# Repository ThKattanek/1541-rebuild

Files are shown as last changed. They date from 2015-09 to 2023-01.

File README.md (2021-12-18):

# 1541-rebuild
Ersetzt den Analogteil einer Floppy 1541 durch ein Micro Controller der Disk Images per SD Karte lesen kann. Mit dieser Hardware ist es möglich ein Board wo der Analogteil defekt ist, durch diese wieder zum laufen zu bringen. Das schreiben ist nun auch schon enthalten. Es wird lediglich die 1541 Platine, diese Hardware und ein 5VDC Netzteil benötigt, oder auch das Originale Netzteil. An der 1541 II Platine muss eine Änderungen vorgenommen werden und zwar die (VIA2 (DC) sockeln.

#### ** Danke [F00K42](https://github.com/fook42) für die Entwicklung der Schreibroutinen für D64 Images. **

### [Letzte Offizelle Version findet ihr hier](https://github.com/ThKattanek/1541-rebuild/releases/latest)

### Hardware / Schaltplan
Die Hardware wird mit KiCad entwickelt. Version 5.1.4 unter Ubuntu.

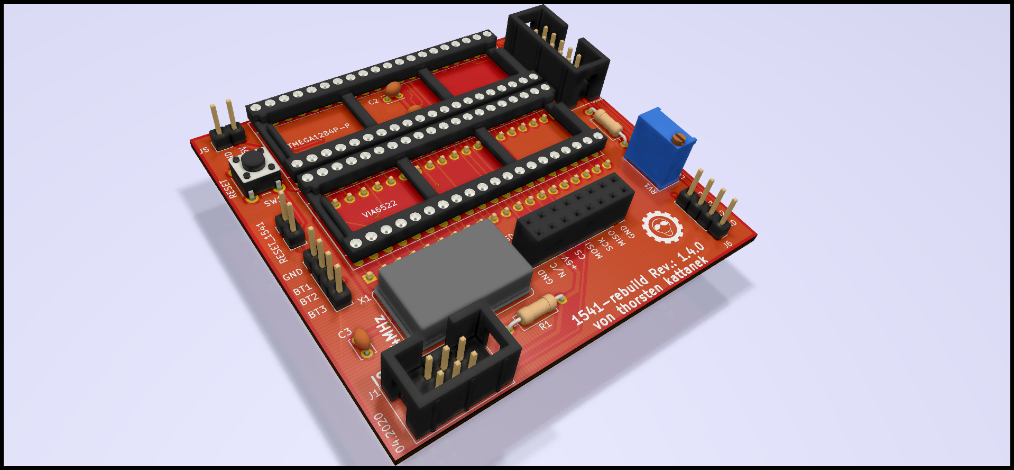
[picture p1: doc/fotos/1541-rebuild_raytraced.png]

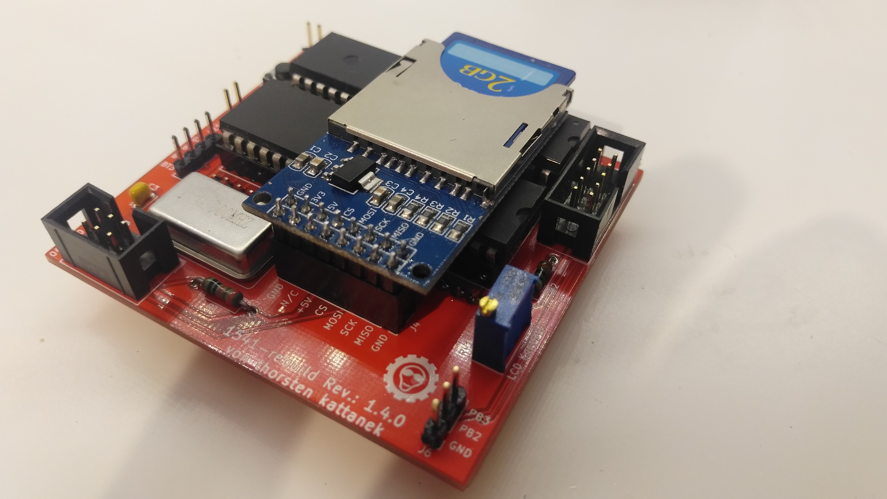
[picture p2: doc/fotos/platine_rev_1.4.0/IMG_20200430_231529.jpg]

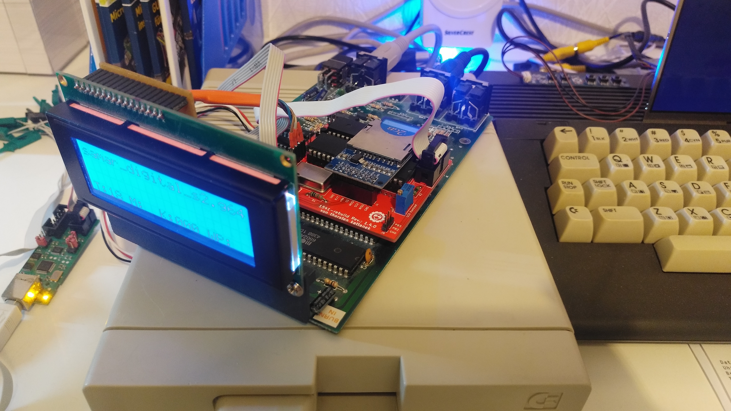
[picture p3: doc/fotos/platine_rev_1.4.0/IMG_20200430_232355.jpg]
 

### Hier der Thread dazu im Forum64
https://www.forum64.de/index.php?thread/59884-laufwerk-der-1541-emulieren

### Einige Videos von der 1541-rebuild in aktion
https://youtu.be/EGB8lYKcW-g

https://www.youtube.com/watch?v=MlbUPTzcQGI&t=36s

https://www.youtube.com/watch?v=gKM73VpHdTw&t=256s

### Verwendete Libs
LCD Ansteuerung von Mikrokontroller.net: http://www.mikrocontroller.net/articles/AVR-GCC-Tutorial/LCD-Ansteuerung

SD/FAT System von Roland Riegel: http://www.roland-riegel.de/sd-reader/

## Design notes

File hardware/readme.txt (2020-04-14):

Die Hardware wurde mit KiCad Version 5.1.4 erstellt.

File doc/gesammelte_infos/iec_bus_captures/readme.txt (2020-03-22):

1541_real_turrican1.vcd -> Mitschnitt vom 2. IEC Port der Floppy (mit echter Floppy Disk)
1541_rebuild_turrican1.vcd -> Mitschnitt vom 2. IEC Port der Floppy (D64 Image vom obigen genannter Disk)
emu64_turrican1.vcd -> VCD Exoprt per Emu64 (V 5.0.18) Debugger (D64 Image vom obigen genannter Disk)

trurrican1-s1.d64 -> erzeugt mit Ultimate 1541_II_Plus (FW: 3.6a (115))

Das Image läuft weder auf 1541 Rebuild noch auch Emu64 5.0.18 -> aber auf Vice -> somit ist zumindest das Image i.o.

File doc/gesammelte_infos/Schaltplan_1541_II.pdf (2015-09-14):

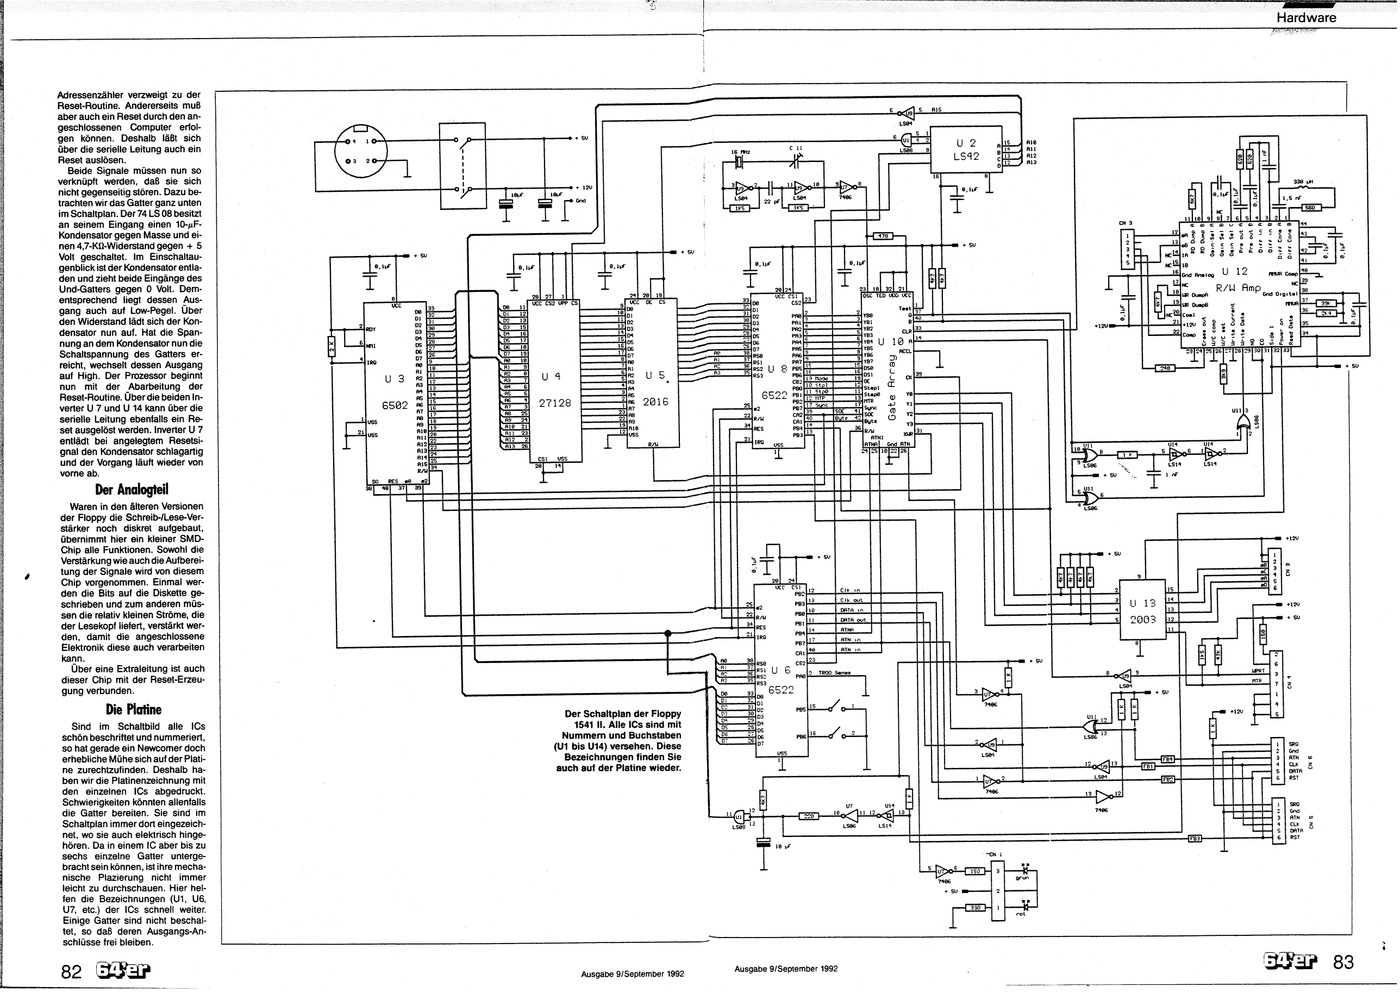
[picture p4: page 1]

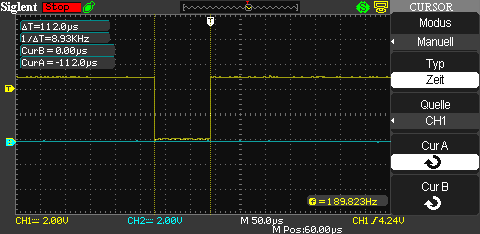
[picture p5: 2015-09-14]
doc/oscilloskope_bilder_real_hardware/sync_time.png

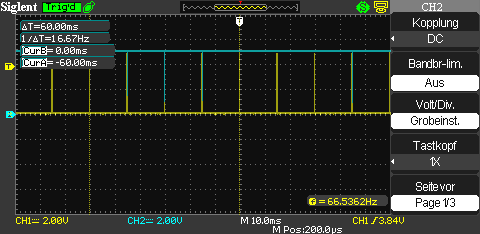
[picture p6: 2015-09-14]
doc/oscilloskope_bilder_real_hardware/byte_ready(blau)_und_SOE.png

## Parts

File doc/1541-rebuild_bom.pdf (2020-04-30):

1541-rebuild_bom

Date: | Do 30 Apr 2020 20:06:55 CEST
Tool: | Eeschema 5.1.4+dfsg1-1
Version: | 1.4.0
Ref | Value | Footprint
C1 | 100n | Capacitor_THT:C_Disc_D3.4mm_W2.1mm_P2.50mm
C2 | 100n | Capacitor_THT:C_Disc_D3.4mm_W2.1mm_P2.50mm
C3 | 100n | Capacitor_THT:C_Disc_D3.4mm_W2.1mm_P2.50mm
IC1 | ATMEGA1284P-P + Sockel | Package_DIP:DIP-40_W15.24mm_Socket_LongPads
IC2 | VIA6522 + Sockel | Package_DIP:DIP-40_W15.24mm_Socket_LongPads
J1 | ISP | Connector_IDC:IDC-Header_2x03_P2.54mm_Vertical
J2 | KEYS | Connector_PinHeader_2.54mm:PinHeader_1x04_P2.54mm_Vertical
J3 | RESET_1541 | Connector_PinHeader_2.54mm:PinHeader_1x02_P2.54mm_Vertical
J4 | SD Card Modul Connector | Connector_PinSocket_2.54mm:PinSocket_2x08_P2.54mm_Vertical
J5 | EXT_5V | Connector_PinHeader_2.54mm:PinHeader_1x02_P2.54mm_Vertical
J6 | IO | Connector_PinHeader_2.54mm:PinHeader_1x03_P2.54mm_Vertical
J7 | LCD Display | Connector_IDC:IDC-Header_2x05_P2.54mm_Vertical
P1 | VIA_PIN_1-20 | Connector_PinHeader_2.54mm:PinHeader_1x20_P2.54mm_Vertical
P2 | VIA_PIN_21-40 | Connector_PinHeader_2.54mm:PinHeader_1x20_P2.54mm_Vertical
R1 | 10k | Resistor_THT:R_Axial_DIN0207_L6.3mm_D2.5mm_P10.16mm_Horizontal
R2 | 150 | Resistor_THT:R_Axial_DIN0207_L6.3mm_D2.5mm_P10.16mm_Horizontal
RV1 | 10k | Potentiometer_THT:Potentiometer_Bourns_3296W_Vertical
SW1 | RESET | Button_Switch_THT:SW_PUSH_6mm_H5mm
X1 | 24Mhz | Oscillator:Oscillator_DIP-14_LargePads
LCD Modul | 20 Zeichen x 4 Spalten | HD44780 2004 LCD Display Modul Anzeige 4x20 Zeichen
SD Card Modul | inkl. Pegelanpassung 3,3V

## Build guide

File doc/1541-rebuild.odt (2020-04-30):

1541-rebuild

von Thorsten Kattanek

Berlin, 01.05.2020

## 1.0 Was ist 1541-rebuild

1541-rebuild ersetzt den mechanisch-analogen Teil der Commodore Floppy 1541 und 1541 II durch eine Elektronik. Die Floppy Disk wird in einem Mikrocontroller emuliert. Die Disk Images werden über eine SD Karte geladen. Die Bedienung erfolgt über 3 Taster und ein LCD Display. Als Mikrocontroller kommt ein Atmega1284P zum Einsatz, der mit 24 MHz getaktet wird.

## 2.0 Beschreibung der Internen Prozesse

### 2.1 Emulation des Schrittmotors

Der Schrittmotor ist der Antrieb für den Schreib- Lesekopf der Floppy. Dieser wird auf die zu zugreifende Spur gefahren. Der Schrittmotor hat 4 Anschlüsse welche an die 4 Spulen des Schrittmotors gehen. Durch geeignete Ansteuerung der Spulen kann der Schrittmotor um ein ganz kleinen Winkel, nach links oder rechts gedreht werden. Die vier Steuersignale für den Schrittmotor werden von dem GateArray 251828 U10 erzeugt. Das GateArray bekommt dafür 2 Signale von der VIA2 diese da wären STP0 und STP1. Mit diesen 2 Signalen kann der Lesekopf um genau eine Halbspur vor oder zurück bewegt werden. Diese beiden Signale muss in unserem Fall der µC auswerten um intern die Virtuelle Spur darstellen zu können.

Hier mal die Signale mit einem Logic Analyzer aufgenommen, wenn die Floppy Disk formatiert wird. Der Lesekopf wird dabei an den Anschlag (BUMP) nach außen gefahren.

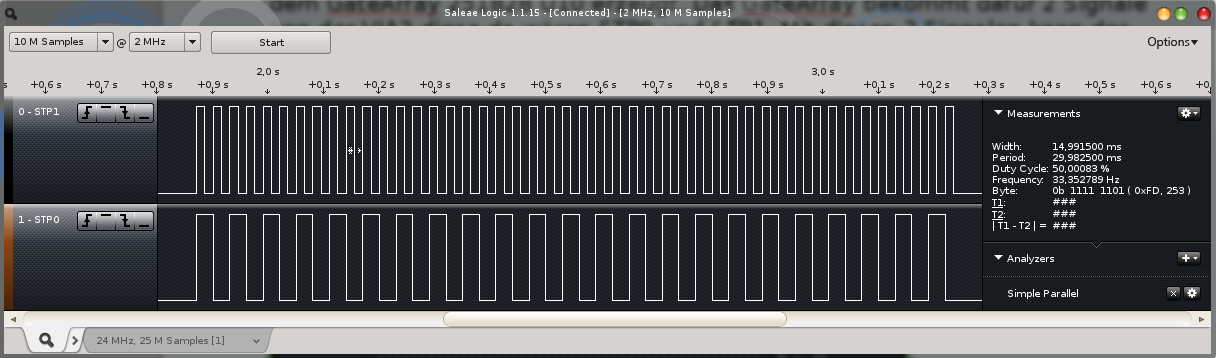
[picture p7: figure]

Die beiden STP Signale sind „verdreht“ am VIA2 angeschlossen. STP1 ist am PB0 und STP0 ist am PB1 angeschlossen. Wenn wir die Signale mal in einer Tabelle aufnehmen sieht man die Wirkungsweise der Signale.

Step | PB1 (STP0) | PB0 (STP1) | Dezimal
0 | 1 | 1 | 3
1 | 1 | 0 | 2
2 | 0 | 1 | 1
3 | 0 | 0 | 0
4 | 1 | 1 | 3
5 | 1 | 0 | 2

Man sieht hier deutlich das der VIA2 nur die beiden PINS „runter zählen“ muss um den Lesekopf nach außen zu bewegen und zwar immer um eine Halbspur.

Zählt die VIA2 hoch fährt der Lesekopf entsprechend nach innen. Steht der Lesekopf nun auf eine „voll“ Spur (Bit 0 der aktuellen Halbspur gelöscht) so müssten sofort die neuen Daten von der aktuellen Spur in das RAM geladen werden. Um das aber zu verhindern und dabei Zeit zu sparen, werden erst neue Daten geladen wenn es 20ms keine Signaländerungen an STP0 und STP1 gegeben hat. Je nach Postion der Spur muss die Schreib-/ Lesegeschwindigkeit der GCR Daten neu gesetzt werden. Dazu mehr weiter unten im Kapitel 2.3.

Das ist eigentlich auch schon alles was man wissen muss um die Signale auszuwerten zu können und den internen Spurzeiger zu setzen.

### 2.2 Emulation des Laufwerkmotors

Der Laufwerksmotor wird gesteuert durch die VIA2 PB2. Ist es High läuft der Motor ist er Low ist er aus. Dieses Signal wird benutzt um das senden der GCR Bytes zu steuern. Ist das Signal High werden aus dem Ringpuffer fleißig die GCR Bytes der aktuellen Spur gesendet. Ist das Signal Low werden nur noch 0 Bytes gesendet. (Keine Flusswechsel da keine Drehung !)

### 2.3 Schreib-/ Lesekopf (GCR Daten)

Gleich erstmal vorweg. Im momentanen Entwicklungszustand unterstützt die 1541-rebuild nur das lesen von einem Disetten Image (d64, g64). Das schreiben und insbesondere das zurückschreiben in einem Disketten Image auf die SD Karte ist noch nicht vollständig implementiert. Es wurde schon auf Machbarkeit geprüft und G64 Dateien konnten beschrieben werden, jedoch ist das ganze in der aktuellen Firmware (1.2.3) sehr unzuverlässig.

Kommen wir nun zum lesen der Daten von einem GCR

## 3.0 Spannungsversorgung

Die Spannungsversorgung erfolgt über ein Steckernetzteil mit 5VDC und 1A. Leider ist das Originale Floppy Netzteil etwas schwachbrüstig. Die Spannung brach mit der Zusatzschaltung auf 4.7V ein. Wenn ich den Datenport komplett auf High gesetzt habe, brach sie sogar auf 4.2V ein. Somit konnte der 251828 intern die Transistoren nicht mehr komplett durchschalten und der Effekt war eine glühende GateArray.

Momentan läuft bei mir die Schaltung auch mit dem Originalen Floppy Netzteil!

## 4.0 Hardware – Aufbauanleitung (Rev. 1.4.0)

## 5.0 Flashen der Firmware (unter Linux)

## 6.0 1541-rebuild Bedienungsanleitung

## 7.0 Quellen

- Die Floppy 1541 von Karsten Schramm

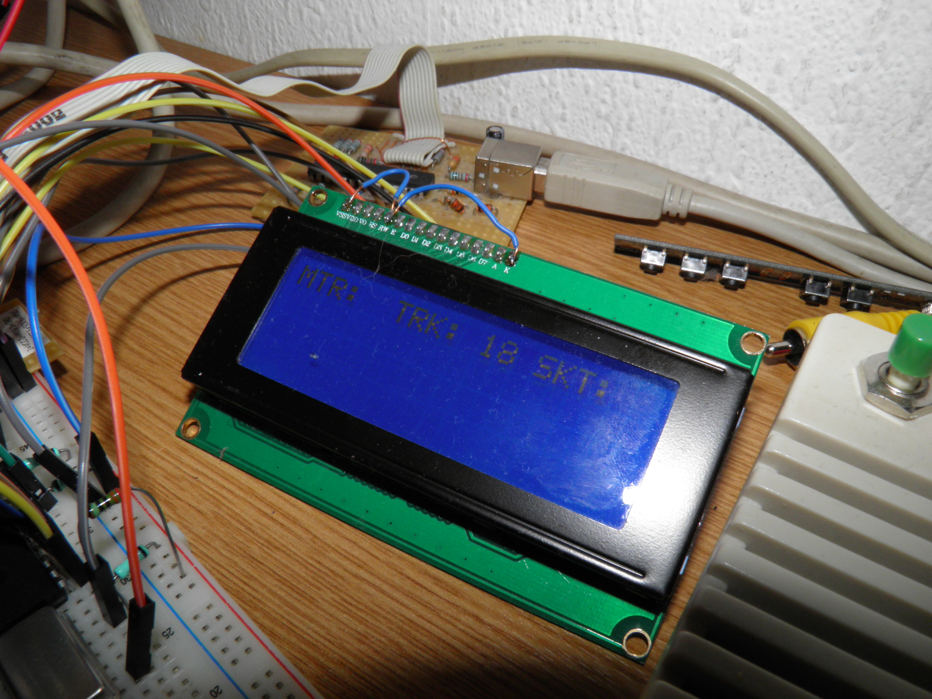
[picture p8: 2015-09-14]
doc/fotos/testaufbau_noch_ohne_sd_karte/P9140091.JPG

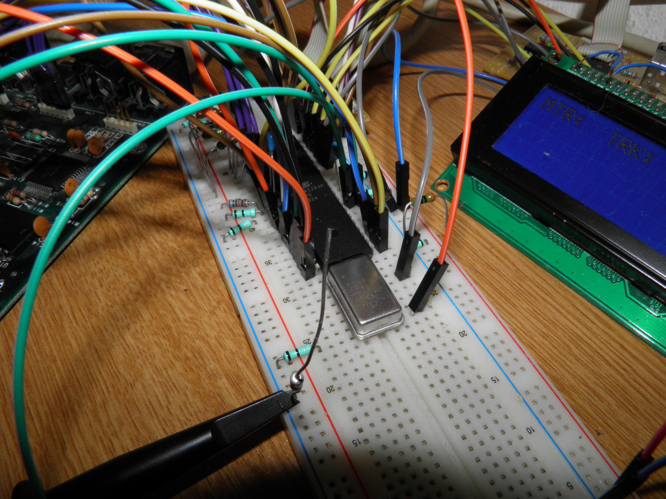
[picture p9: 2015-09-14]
doc/fotos/testaufbau_noch_ohne_sd_karte/P9140089.JPG

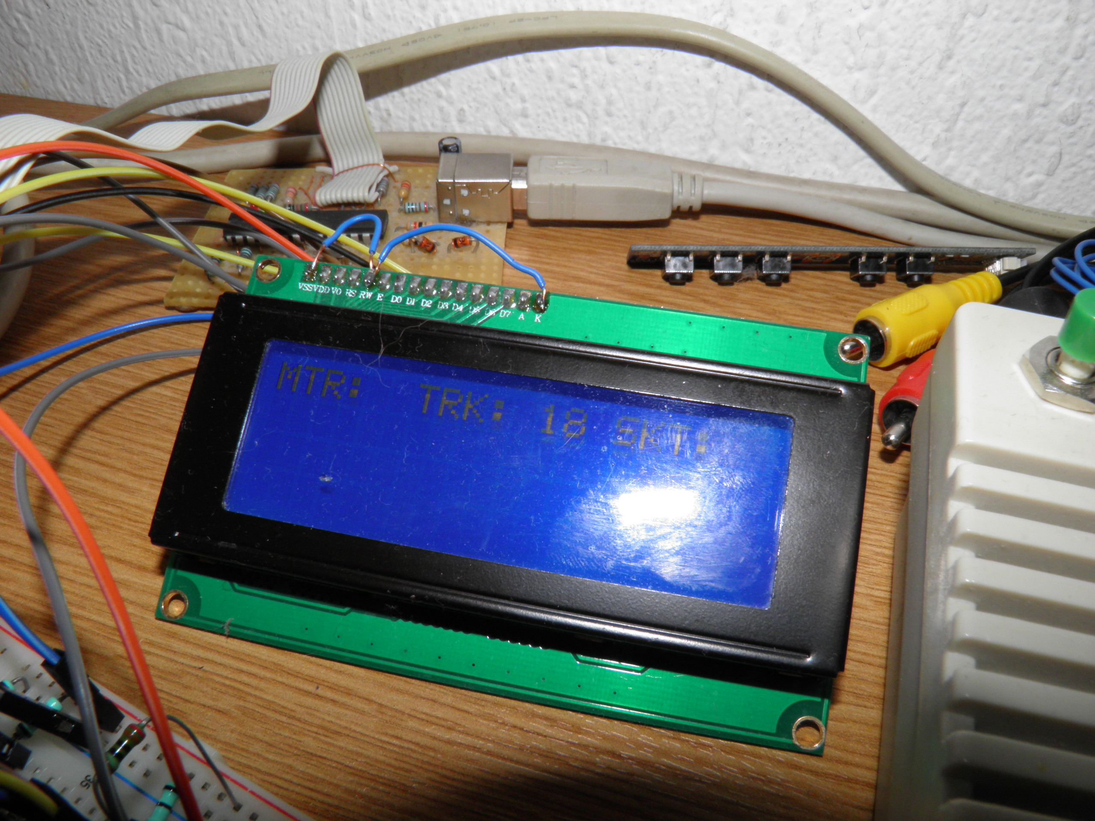
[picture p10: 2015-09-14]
doc/fotos/testaufbau_noch_ohne_sd_karte/P9140090.JPG

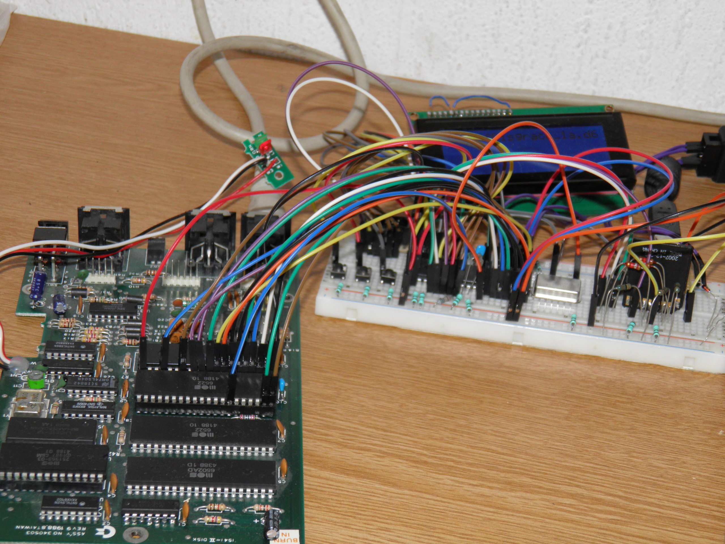
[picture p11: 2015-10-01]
doc/fotos/testaufbau_mit_sd_karte/PA010091.JPG

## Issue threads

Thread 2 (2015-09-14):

SD Karten zugriff einbauen

ThKattanek, 2015-09-14:
Die Lib von Roland Riegel "http://www.roland-riegel.de/sd-reader/" benutzen.

ThKattanek, 2015-09-14:
Hab da mal angefangen das einzubauen. Das ganze ist elektronisch recht wackelig aber für die ersten Versuche sollte das reichen.

ThKattanek, 2015-09-21:
Läuft so ganz stabil, werd aber mal sehen wie ich die 3,3 V erzeuge. Mit Zener Diode ??

Closed 2015-10-05.

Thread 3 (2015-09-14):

Aufbau ohne 12V Testen

ThKattanek, 2015-09-14:
Den aktuellen Aufbau ohne 12V Testen. Labor Netzteil dafür benutzen. Stromverbrauch/Leistung ermitteln

ThKattanek, 2015-09-14:
Das ganze funktioniert mit meiner Platine auch ohne 12V. Der Aufbau plus 1541II Platine zieht bei 5V einen Strom von 600mA. Macht 3Watt.

ThKattanek, 2015-09-21:
Wichtig ! Das original Netzteil geht dabei in die Knie. Steckernetzteil mit 5VDC/1A geht super.

Closed 2015-09-21.

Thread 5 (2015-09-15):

Steppermotror und Diskmotor neue Abfrage

ThKattanek, 2015-09-15:
Der Steppermotor soll nur noch direkt von der VIA2 abgefragt werden. Einsparung von 2 PINS.
STP0 + STP1 an PB0 und PB1
Das Motorsignal soll auch direkt an der VIA2 abgenimmen werden und an PB2 geführt werden.
Schaltplan und Firmware sind anzupassen.

ThKattanek, 2015-09-21:
Erledigt.

Closed 2015-09-21.

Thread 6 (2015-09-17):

D64 Image laden und Spur 18 als GCR Daten ins RAM laden

ThKattanek, 2015-09-17:
Dazu muss der Testtrack im includefile raus und die IRQ Routine muss aus dem Speicher lesen.

ThKattanek, 2015-09-21:
Das ganze funktioniert jetzt schon mit G64 Dateien.

ThKattanek, 2015-09-28:
Es läuft nun auch D64. Nur leider mit Lesefehler 23. Das ganze sieht so aus als ob die erzeugten GCR Daten auch 0xFF also SYNC BYTES enthalten.

ThKattanek, 2015-09-29:
Wurde geklärt. Ein einzelnes 0xFF sagt nicht das es ein SYNC Byte ist !!

Closed 2015-09-29.

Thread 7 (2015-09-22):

Fehler in Dateiauswahl

ThKattanek, 2015-09-22:
Am Ende der Liste wird durch nocmaliges drücken auf runter/rechts die Datei nochmal angezeigt und verschwindet dann.

ThKattanek, 2020-05-27:
Neue GUI wurde eingebaut.
Erledigt!

Closed 2020-05-27.

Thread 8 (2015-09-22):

Steppermotor

ThKattanek, 2015-09-22:
Die Auswertung des Steppermotors läuft schief. Es ist nicht möglich eine andere Spur ausser der beim laden eingestellte zu lesen.

ThKattanek, 2015-09-22:
Werde das mal mit LA ankucken. Dazu werde ich mal ein PIN des Atmegas als Debug Signal missbrauchen und mir das ankucken. Erstmal das Debug Signal Togglen bei jeden IRQ, dann wenn inc und dec erkannt wird und zu letzt in der main. Da geht bestimmt was verloren.

ThKattanek, 2015-09-22:
Test. Den Standard Track auf 1 und dann das Verzeichnis lesen. Bei einem Spurwechsel kein neues laden eines Track. Dann sollte der Track immer von 1 auf 18 fahren !

ThKattanek, 2015-09-29:
Stepperauswertung läuft nun. Evtl. noch so Ändern das gewartet wird wenn beide Signale Low sind.

ThKattanek, 2015-10-05:
Beide Signale Low müssen nicht sein. Deshalb wird das doch nicht so abgefragt.

Closed 2015-10-05.

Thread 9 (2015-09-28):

Komisches Verhalten beim Lesen

ThKattanek, 2015-09-28:
Lesefehler immer genau an der selben Stelle im Image !
Geprüft mit Diskmonitor und Fehlermatrix anzeigen lassen.
Unteschiedliche Images unterschieche Fehler. Aber gleiche Fehlerbild immer wieder bei der selben Diskette. ???

ThKattanek, 2015-09-28:
Per Logic Analyzer bin ich dem ganzen schon mal etwas näher gekommen. Es müssen 0xFF Bytes also SYNC BYTES erkannt werden. Mann sieht deutlich mitten im Block die SYNC Maker. Und genau ab diesen bricht die kodierung ab. Hier die 2 Blocks 4 und 5 von Spur 1 des Images Love_S1.d64. Entweder werden die 0xFF beim GCR Konvertieren mit eingebaut oder es werden fälschlicherweise welche erkannt.
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

ThKattanek, 2015-09-29:
OK. Ich glaube ich habe das Problem gefunden. Es müssen mindesten 10 Einsens hintereinander sein damit ein SYNC erzeugt wird. ! Es ist normal das im GCR Code bis zu 9 Einsen hintereinader vorkommen können. Es reicht also nicht einfach bei einem 0xFF zu suchen. Nein es müssen mind. 2 Stück sein !! (zumidest bei den D64 Images)

ThKattanek, 2015-09-29:
Also, muss geprüft werden, wenn ein SYNC Byte anliegt und ob das vorige auch 0xFF war.
Lösung erstmal mit old_gcr ...

ThKattanek, 2015-09-30:
Sieht doch gut aus. Das ganze schein nun zu laufen.
Vorher viele viele Lesefehler ...
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
Und nun alles i.O.
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
Getestet mit love_s1.d64

Closed 2015-09-30.

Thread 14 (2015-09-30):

OE Signal in Schaltplan einfügen.

ThKattanek, 2015-09-30:
Auch wenn es noch nicht eingebaut wird, sollte der erste Prototyp die Leitung besitzen. Wer weiss was noch alles kommt.

ThKattanek, 2015-09-30:
Sollte an PC5 gehen. Damit wäre nur noch PC7 frei !

Closed 2015-09-30.

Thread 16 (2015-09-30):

Floppy springt nach C64 Reset nicht mehr an

ThKattanek, 2015-09-30:
Die Floppy läuft nicht mehr an wenn ein Reset am C64 gemacht wurde. Floppy muss kurz vom Strom genommen werden. Tritt aber nicht immer auf !!

ThKattanek, 2015-09-30:
Wird der C64 aber aus und wieder angeschaltet funktioniert die Floppy wieder. (Macht dann ja einen Reset)

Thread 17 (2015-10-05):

Versuch effizenter einen Track zu laden

ThKattanek, 2015-10-05:
Mit der folgenden Methode sollte es möglich sein auch zwischen dem laden einer komplette Spur die Spur sofort zu wechseln. Also diese muss nicht jedes mal komplett geladen werden auch wenn der Kopf nur kurz drüber rutscht. Des weiteren wird verhindert das beim laden einer Spur durch überschneidung des lesens von der selbigen es zu "Müll" kommt.

Wegfallen lassen der STEPPER_DELAY_TIME
```
byte AnzahlBlöcke
byte BlockRest

byte *akt_track_adresse

Hauptschleife()
{
   Stepper-Auswerten

   Wenn == Spurwechsel (nicht bei Halbspur)
   {
      Flag Setzen das nur noch GAP(0x55) Bytes gesendet werden
      Länge des neuen Track ermitteln, daraus Anzahl der zu ladenden vollen 256 Byte Blöcke und den Rest (AnzahlBlöcke, BlockRest)
      akt_track_adresse = gcr_track;
   }

   Wenn (Anzahl Blöcke > 0 oder Rest > 0)
   {
      if(Anzahl Blöcke > 0)
      {
         nächsten 256 Byte nach akt_track_adresse laden
         akt_track_adresse += 256
         Anzahl Blöcke --;
         if(Anzahl Blöcke == 0 && Rest == 0)
         {
            Flag löschen das wieder vom Track gelesen und wieder gesendet werden kann
         }
      }
      else if (Rest > 0)
      {
         Rest nach akt_track_adresse laden
         Flag löschen das wieder vom Track gelesen und wieder gesendet werden kann
      }
   }
}
```

Closed 2015-10-05.

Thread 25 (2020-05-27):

Drehimpulsgeber unterstützung

ThKattanek, 2020-05-27:
Es soll ein Drehimpulsgeber, anstatt der Button 1 und 2 unterstützt werden.

ThKattanek, 2020-05-27:
Umschaltung durch gedrückt halten der Enter Taste beim Starten. Ausgabe auf LCD welcher Modus gerade ausgewählt ist.

ThKattanek, 2020-05-27:
Die Überprüfung auf einen gedrückten Button3 erfolgt sofort nach der Initialisierung der Hardware, aber noch bevor die SD Karte initialisiert wird.

ThKattanek, 2020-05-27:
Das ganze soll im EEPROM gespeichert werden!

Closed 2020-06-03.

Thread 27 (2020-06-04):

Demo Edge of Disgrace bleibt bei Seite 1b Track 7 mit SpeedDOS hängen

Doctor-B, 2020-06-04:
Die Demo Edge of Disgrace bleibt bei Seite 1b Track 7 mit SpeedDOS hängen. Es ist deutlich der parallel angeschlossene Steppermotor zu hören, aber auf dem LCD bleibt die Trackanzeige bei 7 stehen. Die Demo bleibt beim Hineinzoomen ins Auge dann stehen. Um den Fehler zu erhalten muss die Demo mit der Disk 0 gestartet werden.
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

ThKattanek, 2020-06-04:
Werde mir das mal die Tage genauer anschauen. Gut ist an der Stelle das es immer an der selben Stelle hängt.

ThKattanek, 2020-06-04:
Zu dumm. Ich habe ja gar kein SpeedDos :( Kann das selber gar nicht nachvollziehen. Mit einem AR läuft das. Wo bekomme ich SpeedDos her?

Doctor-B, 2020-06-08:
Entweder selber bauen (Parallelkabel und die ROMs) oder ich kann Dir meins zum Testen leihen.

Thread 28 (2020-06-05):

SD Karten Geschwindigkeitstest einbauen.

ThKattanek, 2020-06-05:
Unter Tools soll man die eingelegte Karte eines Geschwindigkeitstest unterziehen können. Und zwar mit den Bedingungen die das 1541-rebuild benötigt. Es soll ein Schreib- und Lesetest erfolgen.

1. Eine Datei schreiben mehrmals hintereinander (10x?)
2. Diese Datei wieder lesen auch (10x?)

Ermittelt werden soll die jeweils kleinste Zeit, die längste und ein Mittelwert.

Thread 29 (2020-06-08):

Fehler bei Insert Image bei längerer Imageliste [mit Taster]

Doctor-B, 2020-06-08:
Auf meiner SD-Karte sind 9 verschiedene Images. Ich benutze noch die Taster und keinen Encoder. Zur einfacheren Fehlerreproduktion befindet sich die 1541alt direkt nach einem Hardwarereset.

Wenn ich nun ein Image außerhalb der sichtbaren Liste auswählen möchte zB auf Position 5, dann drücke ich 4 mal nach unten. Dabei bleibt die angezeigte Image-Liste unverändert (Positionen 1-4 sind weiterhin sichtbar) und es erscheint oben recht ein Dreieck(Pfeil). (*) Drücke ich ein weiteres mal nach unten dann springt die Liste um zwei Einträge nach unten auf Eintragposition 6 (Positionen 3-6 sind sichtbar).

(*) Wählen ich in diesem Zusatnd das Image aus, dann wird Image der Position 4 ausgewählt.

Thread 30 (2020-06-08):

Reproduzierbarer Absturz beim Formatieren von Spur 36-41 mit "Ultraformat"

inschenioer, 2020-06-08:
Ultraformat V1.0 aus 64'er SH 25, S.65ff lässt den Atmel beim Formatieren von Spur 36-41 reproduzierbar abstürzen. Auch wenn man "Ganze Disk formatieren" auswählt, stürzt der Controller bei Spur 36 dann ab.

Ultraformat an sich ist sicher nicht so wichtig. Es ist aber vielleicht ein Hinweis auf einen Bug, der auch noch andere Auswirkungen hat.

ThKattanek, 2020-06-09:
Das schaue ich mir mal an.

fook42, 2021-12-23:
das Problem ist hierbei das Image ... sowohl D64 als auch G64-Images können "bis zu 42" Tracks beinhalten..
die meisten Disk-Images haben aber nur 35 Tracks vorbelegt, so dass dort auch die Anfangs-Adressen bzw. die Strukturen für die höheren Tracks fehlen (insbesondere beim G64-format muss im Header sowohl der Anfang eines jeden Tracks als auch sein Speed-Index vermerkt sein) - hierbei sind diese Werte dann mit Nullen aufgefüllt.
Die 1541-rebuild Software weiss davon nichts und versucht trotzdem das Start-Offset und die Bitgeschwindigkeit aus dem Header zu lesen und benutzt die Zahl dort stumpf ohne sie zu überprüfen.

Problem: da das ursprüngliche Image die zusätzlichen Tracks (36-42) nicht besitzt, können sie auch nicht adressiert werden
Lösung: Erweiterung des Disk-Images um diese zusätzlichen Tracks - am Besten schon beim Einlesen/Auswählen des Images.
+ Erzeugung der notwendigen Header-Einträge.

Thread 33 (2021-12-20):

D64-Diskwechsel wird nicht erkannt

fook42, 2021-12-20:
Problem, dass manche Loader (alle?) über die Floppy-ID im Header eines jeden Tracks erkennen, ob die gleiche Diskette noch im Laufwerk liegt oder eine andere (bzw. andere Seite) eingelegt wurde.
D64 enthält diese Information nicht - beim "generieren" der GCR-Daten wird immer die gleiche Floppy-ID weitergegeben.

ThKattanek, 2021-12-21:
Erledigt durch fook42

Closed 2021-12-21.

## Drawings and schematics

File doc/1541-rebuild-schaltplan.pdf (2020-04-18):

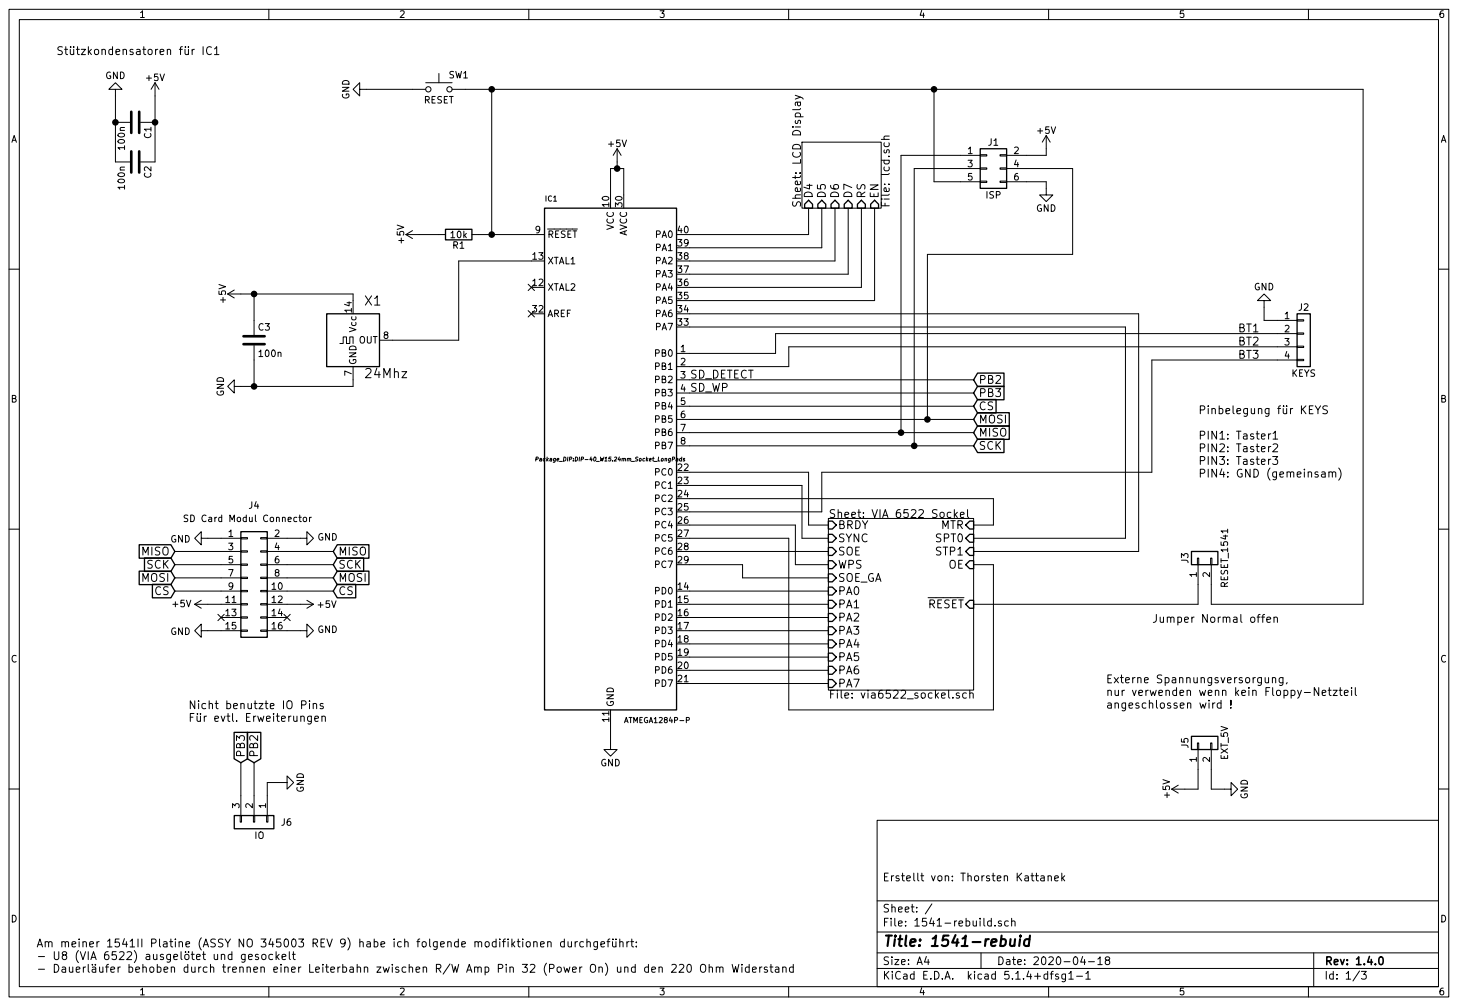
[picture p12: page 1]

File: 1541-rebuild.sch Sheet: / Erstellt von: Thorsten Kattanek Sheet: VIA 6522 Sockel
File: via6522_sockel.sch PA0 PA1 PA2 PA3 PA4 PA5 PA6 PA7 BRDY
SYNC

7 OUT 8 X1
J4 SD Card Modul Connector GND

BT3 Nicht benutzte IO Pins

Externe Spannungsversorgung,
nur verwenden wenn kein Floppy-Netzteil
angeschlossen wird !

Am meiner 1541II Platine (ASSY NO 345003 REV 9) habe ich folgende modifiktionen durchgeführt:
- U8 (VIA 6522) ausgelötet und gesockelt
- Dauerläufer behoben durch trennen einer Leiterbahn zwischen R/W Amp Pin 32 (Power On) und den 220 Ohm Widerstand

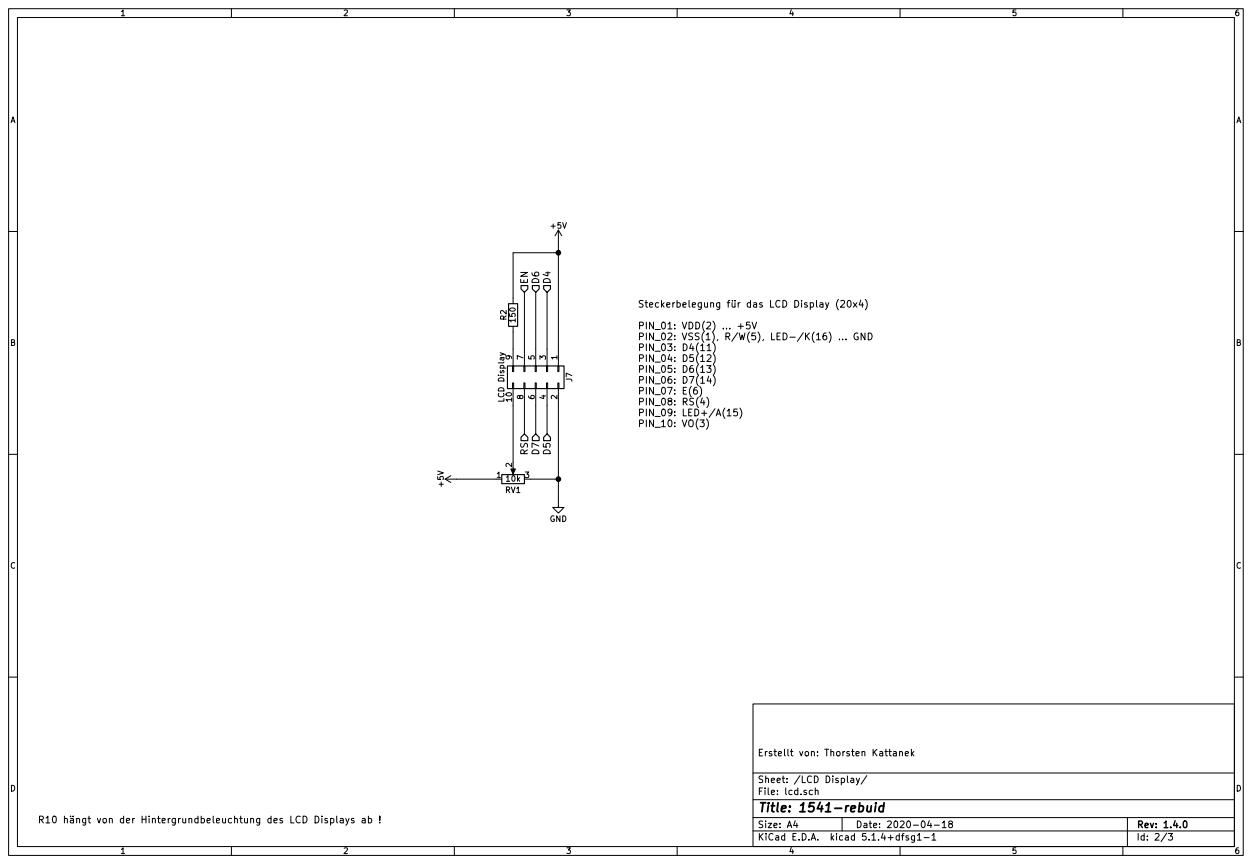
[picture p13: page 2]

Steckerbelegung für das LCD Display (20x4)

File: lcd.sch Sheet: /LCD Display/ Erstellt von: Thorsten Kattanek

R10 hängt von der Hintergrundbeleuchtung des LCD Displays ab !

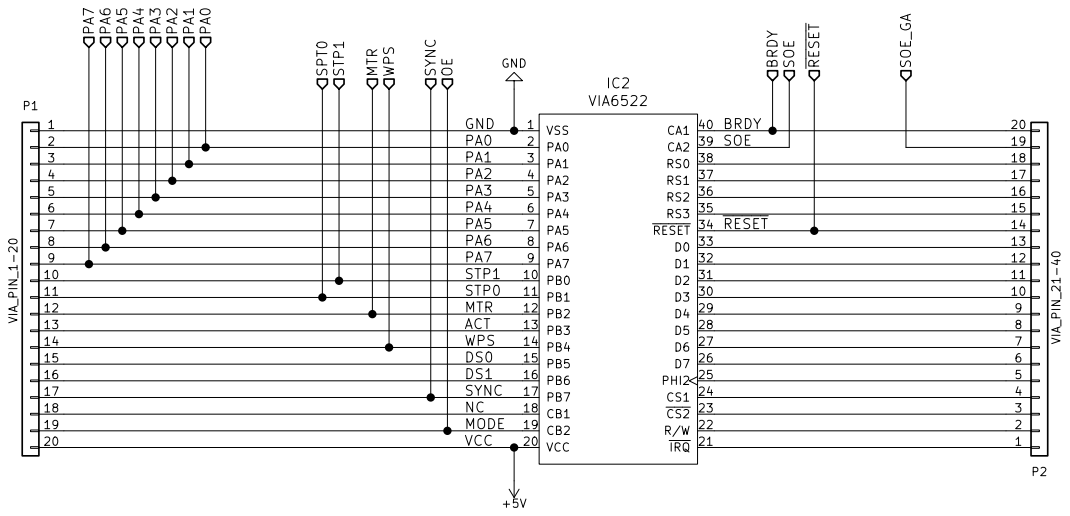
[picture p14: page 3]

File: via6522_sockel.sch Sheet: /VIA 6522 Sockel/ Erstellt von: Thorsten Kattanek 1

17
16

10 | | | STP1 | 11
11 | | | STP0 | 10
12 | | | ACT MTR
13
14 | | WPS
15
16 | | DS1
17 | | SYNC
18 | | NC

MODE

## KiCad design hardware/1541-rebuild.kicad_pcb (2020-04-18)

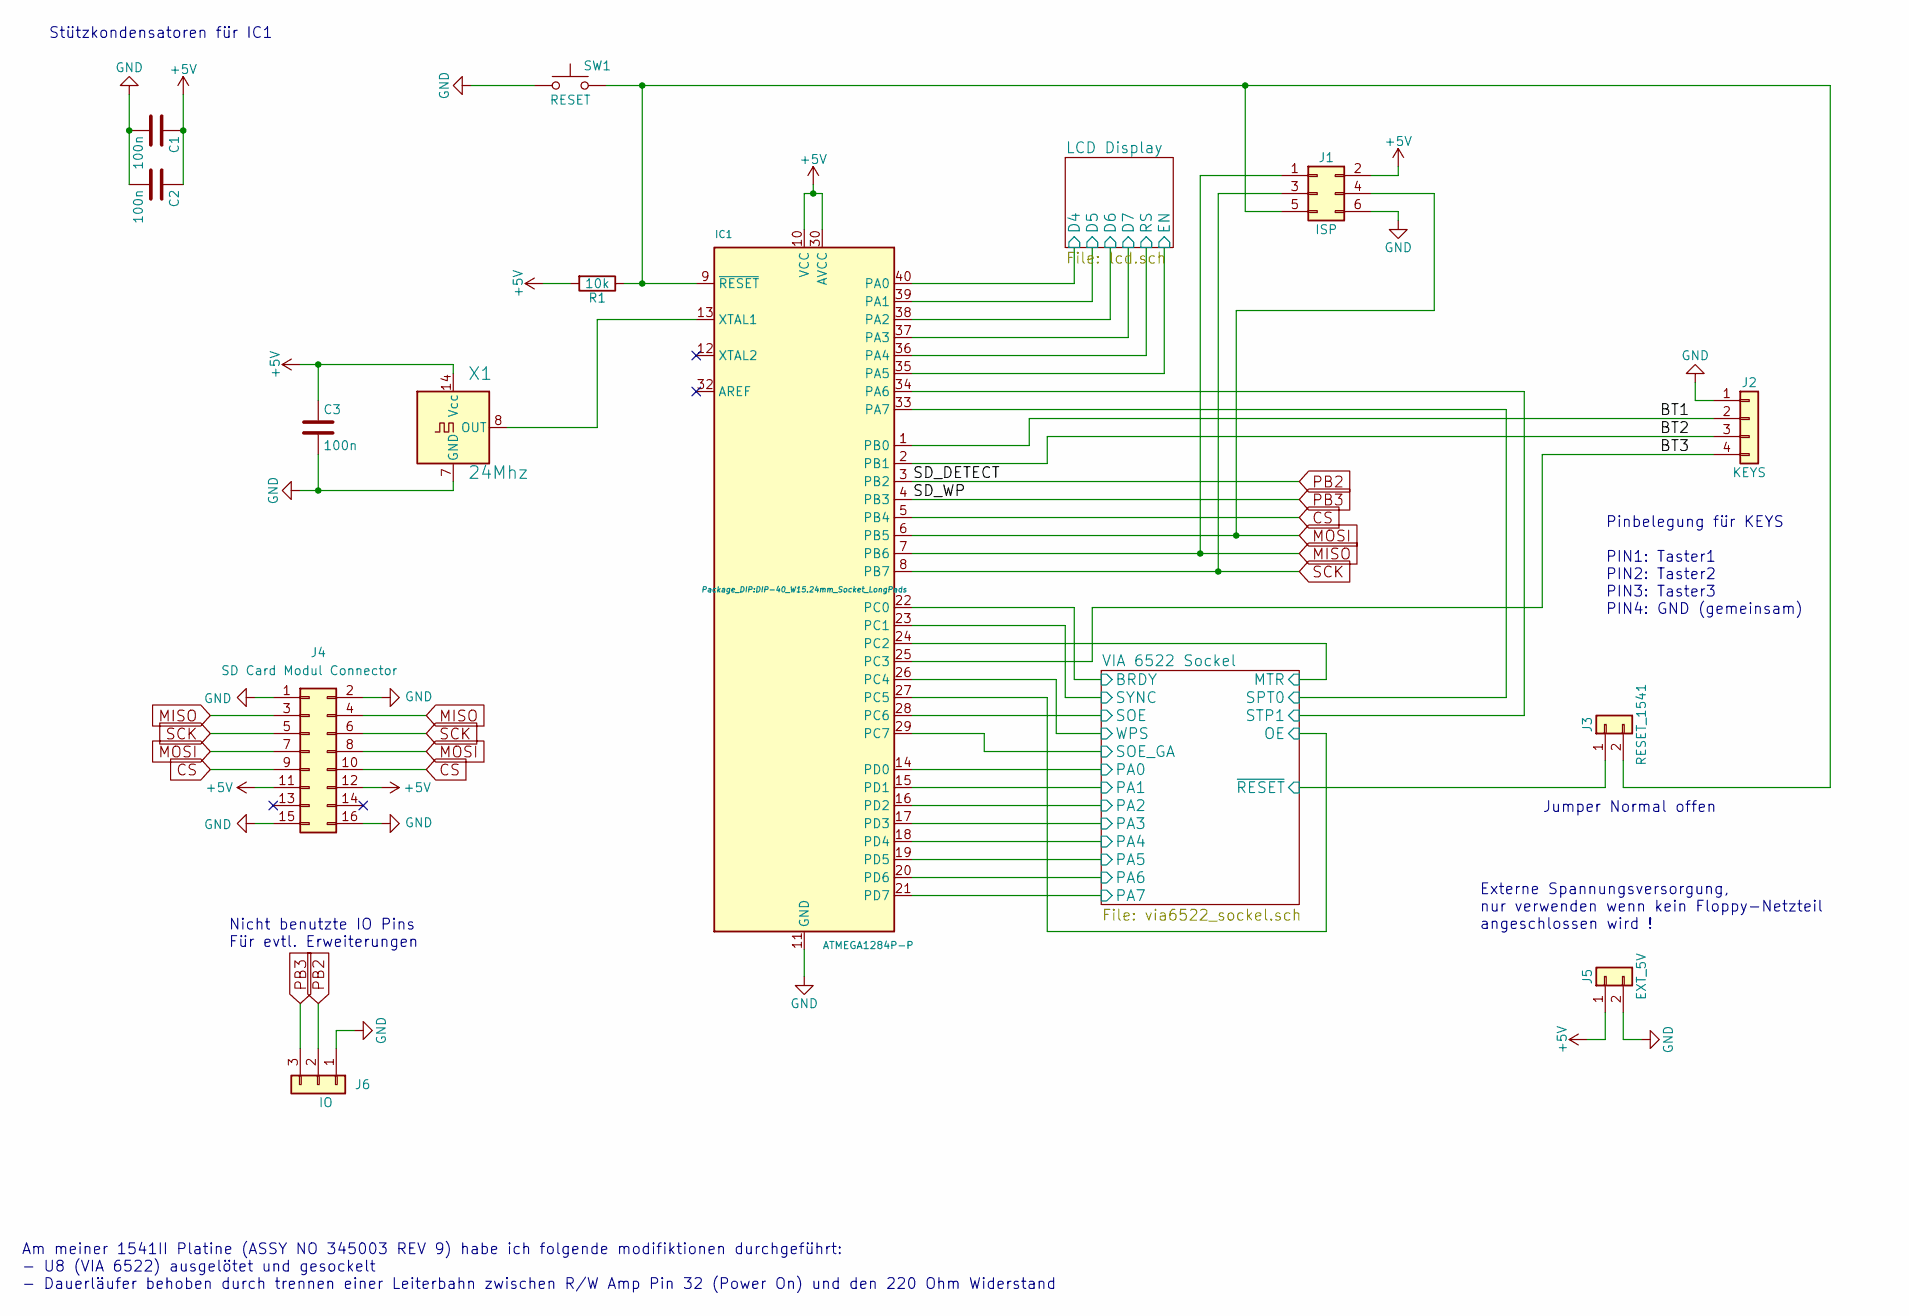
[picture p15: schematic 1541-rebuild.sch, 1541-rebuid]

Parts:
C1, C2, C3: 100n; C_Disc_D3.4mm_W2.1mm_P2.50mm
IC1: ATMEGA1284P-P; DIP-40_W15.24mm_Socket_LongPads
J1: ISP; IDC-Header_2x03_P2.54mm_Vertical
J2: KEYS; PinHeader_1x04_P2.54mm_Vertical
J3: RESET_1541; PinHeader_1x02_P2.54mm_Vertical
J4: SD Card Modul Connector; PinSocket_2x08_P2.54mm_Vertical
J5: EXT_5V; PinHeader_1x02_P2.54mm_Vertical
J6: IO; PinHeader_1x03_P2.54mm_Vertical
R1: 10k; R_Axial_DIN0207_L6.3mm_D2.5mm_P10.16mm_Horizontal
SW1: RESET; SW_PUSH_6mm_H5mm
X1: 24Mhz; Oscillator_DIP-14_LargePads

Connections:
+5V: C1.1, C2.1, C3.1, IC1.10 (VCC), IC1.30 (AVCC), J1.2, J4.11, J4.12, J5.1, R1.2, X1.14 (Vcc); also elsewhere on the board
/BT1: IC1.1 (PB0), J2.2
/BT2: IC1.2 (PB1), J2.3
/BT3: IC1.25 (PC3), J2.4
/LCD Display/D4: IC1.40 (PA0); also elsewhere on the board
/LCD Display/D5: IC1.39 (PA1); also elsewhere on the board
/LCD Display/D6: IC1.38 (PA2); also elsewhere on the board
/LCD Display/D7: IC1.37 (PA3); also elsewhere on the board
/LCD Display/EN: IC1.35 (PA5); also elsewhere on the board
/LCD Display/RS: IC1.36 (PA4); also elsewhere on the board
/VIA 6522 Sockel/BRDY: IC1.22 (PC0); also elsewhere on the board
/VIA 6522 Sockel/MTR: IC1.24 (PC2); also elsewhere on the board
/VIA 6522 Sockel/OE: IC1.27 (PC5); also elsewhere on the board
/VIA 6522 Sockel/PA0: IC1.14 (PD0); also elsewhere on the board
/VIA 6522 Sockel/PA1: IC1.15 (PD1); also elsewhere on the board
/VIA 6522 Sockel/PA2: IC1.16 (PD2); also elsewhere on the board
/VIA 6522 Sockel/PA3: IC1.17 (PD3); also elsewhere on the board
/VIA 6522 Sockel/PA4: IC1.18 (PD4); also elsewhere on the board
/VIA 6522 Sockel/PA5: IC1.19 (PD5); also elsewhere on the board
/VIA 6522 Sockel/PA6: IC1.20 (PD6); also elsewhere on the board
/VIA 6522 Sockel/PA7: IC1.21 (PD7); also elsewhere on the board
/VIA 6522 Sockel/SOE: IC1.28 (PC6); also elsewhere on the board
/VIA 6522 Sockel/SOE_GA: IC1.29 (PC7); also elsewhere on the board
/VIA 6522 Sockel/SPT0: IC1.33 (PA7); also elsewhere on the board
/VIA 6522 Sockel/STP1: IC1.34 (PA6); also elsewhere on the board
/VIA 6522 Sockel/SYNC: IC1.23 (PC1); also elsewhere on the board
/VIA 6522 Sockel/WPS: IC1.26 (PC4); also elsewhere on the board
/VIA 6522 Sockel/~RESET: J3.1; also elsewhere on the board
CS: IC1.5 (PB4), J4.9, J4.10
GND: C1.2, C2.2, C3.2, IC1.11 (GND), IC1.31 (GND), J1.6, J2.1, J4.1, J4.2, J4.15, J4.16, J5.2, J6.1, SW1.1, X1.7 (GND); also elsewhere on the board
MISO: IC1.7 (PB6), J1.1, J4.3, J4.4
MOSI: IC1.6 (PB5), J1.4, J4.7, J4.8
unnamed: IC1.9 (~RESET), J1.5, J3.2, R1.1, SW1.2
unnamed: IC1.13 (XTAL1), X1.8 (OUT)
PB2: IC1.3 (PB2), J6.2
PB3: IC1.4 (PB3), J6.3
SCK: IC1.8 (PB7), J1.3, J4.5, J4.6

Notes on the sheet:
Am meiner 1541II Platine (ASSY NO 345003 REV 9) habe ich folgende modifiktionen durchgeführt: - U8 (VIA 6522) ausgelötet und gesockelt - Dauerläufer behoben durch trennen einer Leiterbahn zwischen R/W Amp Pin 32 (Power On) und den 220 Ohm Widerstand
Stützkondensatoren für IC1
Jumper Normal offen
Pinbelegung für KEYS PIN1: Taster1 PIN2: Taster2 PIN3: Taster3 PIN4: GND (gemeinsam)
Externe Spannungsversorgung, nur verwenden wenn kein Floppy-Netzteil angeschlossen wird !
Nicht benutzte IO Pins Für evtl. Erweiterungen

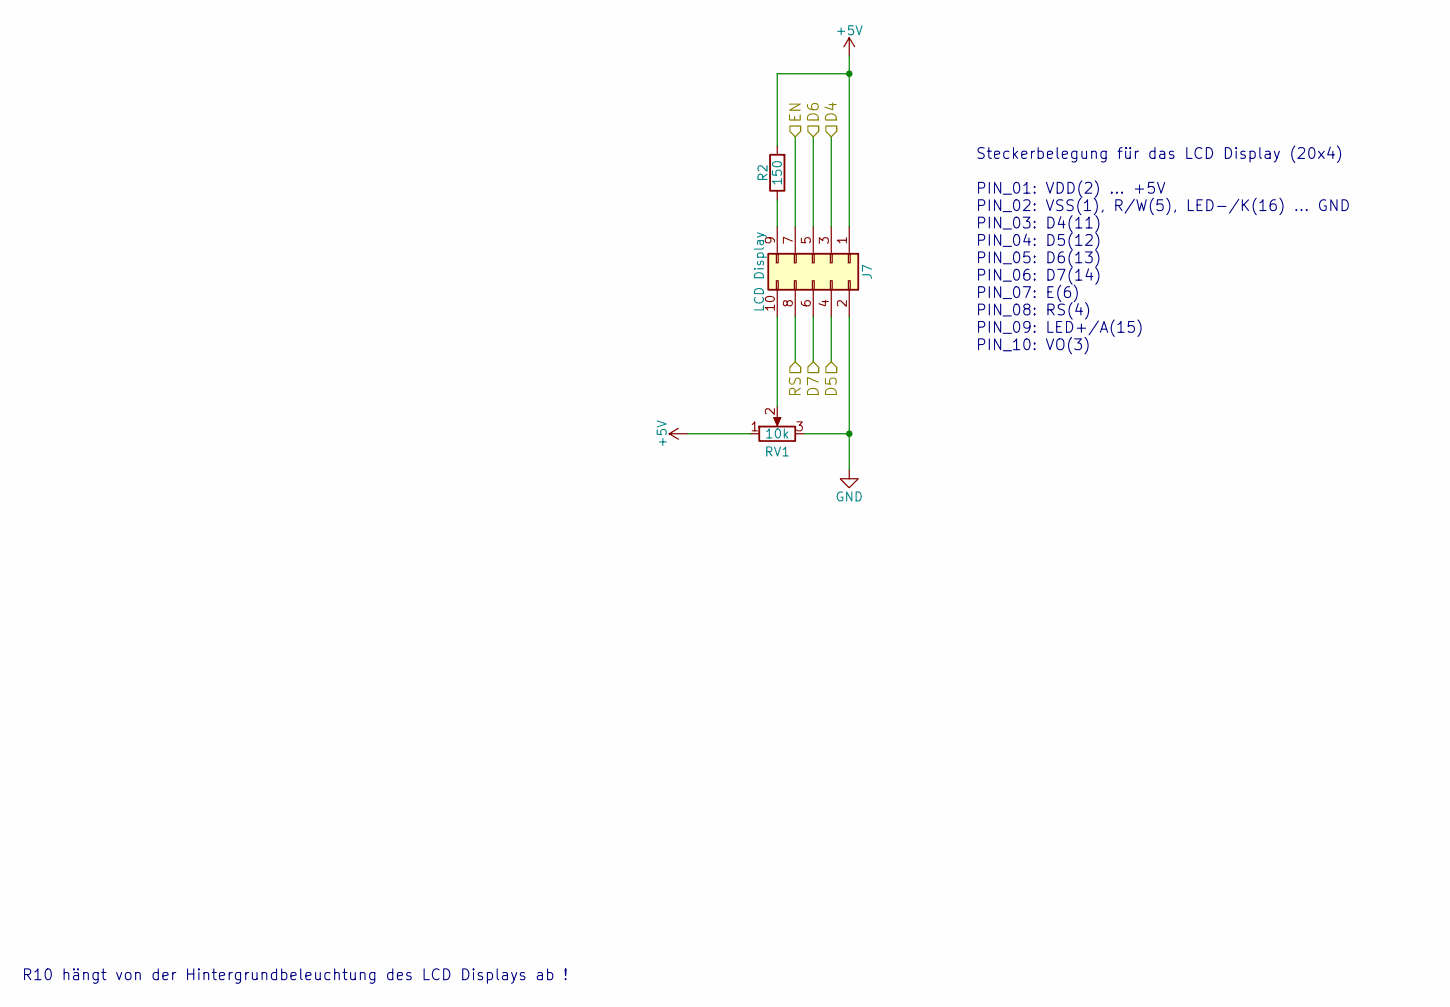
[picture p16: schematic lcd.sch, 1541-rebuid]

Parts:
J7: LCD Display; IDC-Header_2x05_P2.54mm_Vertical
R2: 150; R_Axial_DIN0207_L6.3mm_D2.5mm_P10.16mm_Horizontal
RV1: 10k; Potentiometer_Bourns_3296W_Vertical

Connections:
+5V: J7.1, R2.2, RV1.1; also elsewhere on the board
/LCD Display/D4: J7.3; also elsewhere on the board
/LCD Display/D5: J7.4; also elsewhere on the board
/LCD Display/D6: J7.5; also elsewhere on the board
/LCD Display/D7: J7.6; also elsewhere on the board
/LCD Display/EN: J7.7; also elsewhere on the board
/LCD Display/RS: J7.8; also elsewhere on the board
GND: J7.2, RV1.3; also elsewhere on the board
unnamed: J7.9, R2.1
unnamed: J7.10, RV1.2

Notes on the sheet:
Steckerbelegung für das LCD Display (20x4) PIN_01: VDD(2) ... +5V PIN_02: VSS(1), R/W(5), LED-/K(16) ... GND PIN_03: D4(11) PIN_04: D5(12) PIN_05: D6(13) PIN_06: D7(14) PIN_07: E(6) PIN_08: RS(4) PIN_09: LED+/A(15) PIN_10: VO(3)
R10 hängt von der Hintergrundbeleuchtung des LCD Displays ab !

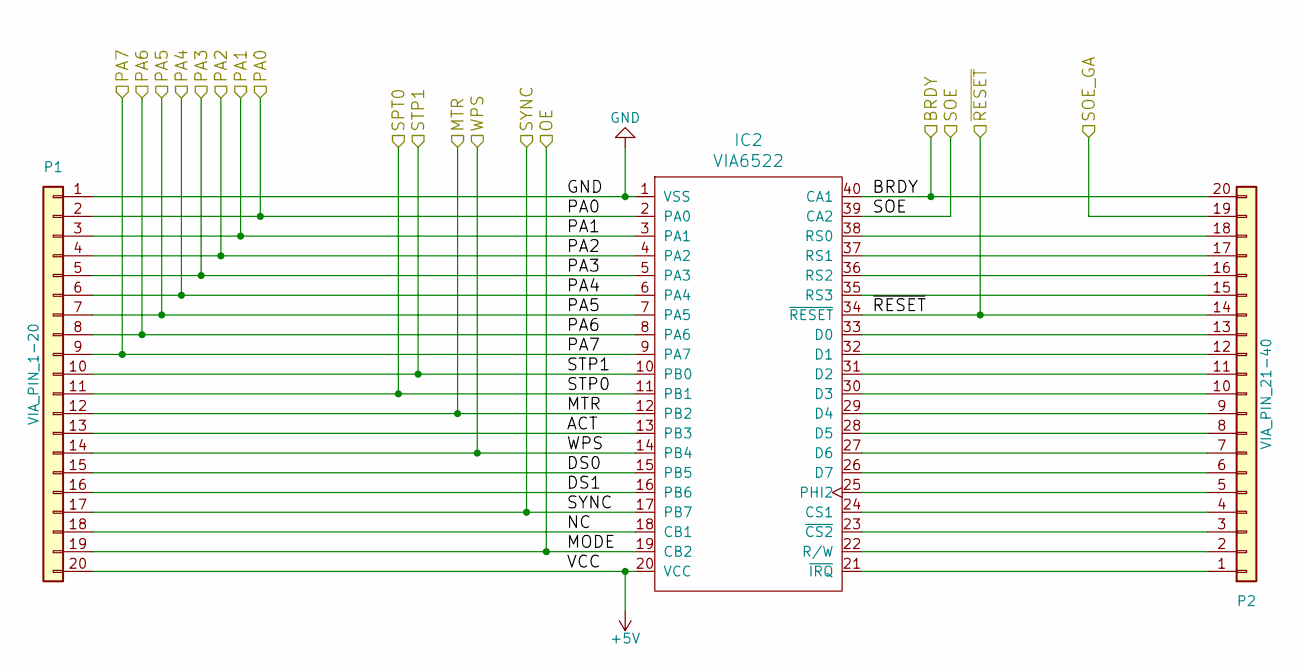
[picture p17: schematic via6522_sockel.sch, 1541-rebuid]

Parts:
IC2: VIA6522; DIP-40_W15.24mm_Socket_LongPads
P1: VIA_PIN_1-20; PinHeader_1x20_P2.54mm_Vertical
P2: VIA_PIN_21-40; PinHeader_1x20_P2.54mm_Vertical

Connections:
+5V: IC2.20 (VCC), P1.20; also elsewhere on the board
/VIA 6522 Sockel/ACT: IC2.13 (PB3), P1.13
/VIA 6522 Sockel/BRDY: IC2.40 (CA1), P2.20; also elsewhere on the board
/VIA 6522 Sockel/DS0: IC2.15 (PB5), P1.15
/VIA 6522 Sockel/DS1: IC2.16 (PB6), P1.16
/VIA 6522 Sockel/MTR: IC2.12 (PB2), P1.12; also elsewhere on the board
/VIA 6522 Sockel/NC: IC2.18 (CB1), P1.18
/VIA 6522 Sockel/OE: IC2.19 (CB2), P1.19; also elsewhere on the board
/VIA 6522 Sockel/PA0: IC2.2 (PA0), P1.2; also elsewhere on the board
/VIA 6522 Sockel/PA1: IC2.3 (PA1), P1.3; also elsewhere on the board
/VIA 6522 Sockel/PA2: IC2.4 (PA2), P1.4; also elsewhere on the board
/VIA 6522 Sockel/PA3: IC2.5 (PA3), P1.5; also elsewhere on the board
/VIA 6522 Sockel/PA4: IC2.6 (PA4), P1.6; also elsewhere on the board
/VIA 6522 Sockel/PA5: IC2.7 (PA5), P1.7; also elsewhere on the board
/VIA 6522 Sockel/PA6: IC2.8 (PA6), P1.8; also elsewhere on the board
/VIA 6522 Sockel/PA7: IC2.9 (PA7), P1.9; also elsewhere on the board
/VIA 6522 Sockel/SOE: IC2.39 (CA2); also elsewhere on the board
/VIA 6522 Sockel/SOE_GA: P2.19; also elsewhere on the board
/VIA 6522 Sockel/SPT0: IC2.11 (PB1), P1.11; also elsewhere on the board
/VIA 6522 Sockel/STP1: IC2.10 (PB0), P1.10; also elsewhere on the board
/VIA 6522 Sockel/SYNC: IC2.17 (PB7), P1.17; also elsewhere on the board
/VIA 6522 Sockel/WPS: IC2.14 (PB4), P1.14; also elsewhere on the board
/VIA 6522 Sockel/~RESET: IC2.34 (~RESET), P2.14; also elsewhere on the board
GND: IC2.1 (VSS), P1.1; also elsewhere on the board
unnamed: IC2.21 (~IRQ), P2.1
unnamed: IC2.22 (R/W), P2.2
unnamed: IC2.23 (~CS2), P2.3
unnamed: IC2.24 (CS1), P2.4
unnamed: IC2.25 (PHI2), P2.5
unnamed: IC2.26 (D7), P2.6
unnamed: IC2.27 (D6), P2.7
unnamed: IC2.28 (D5), P2.8
unnamed: IC2.29 (D4), P2.9
unnamed: IC2.30 (D3), P2.10
unnamed: IC2.31 (D2), P2.11
unnamed: IC2.32 (D1), P2.12
unnamed: IC2.33 (D0), P2.13
unnamed: IC2.35 (RS3), P2.15
unnamed: IC2.36 (RS2), P2.16
unnamed: IC2.37 (RS1), P2.17
unnamed: IC2.38 (RS0), P2.18

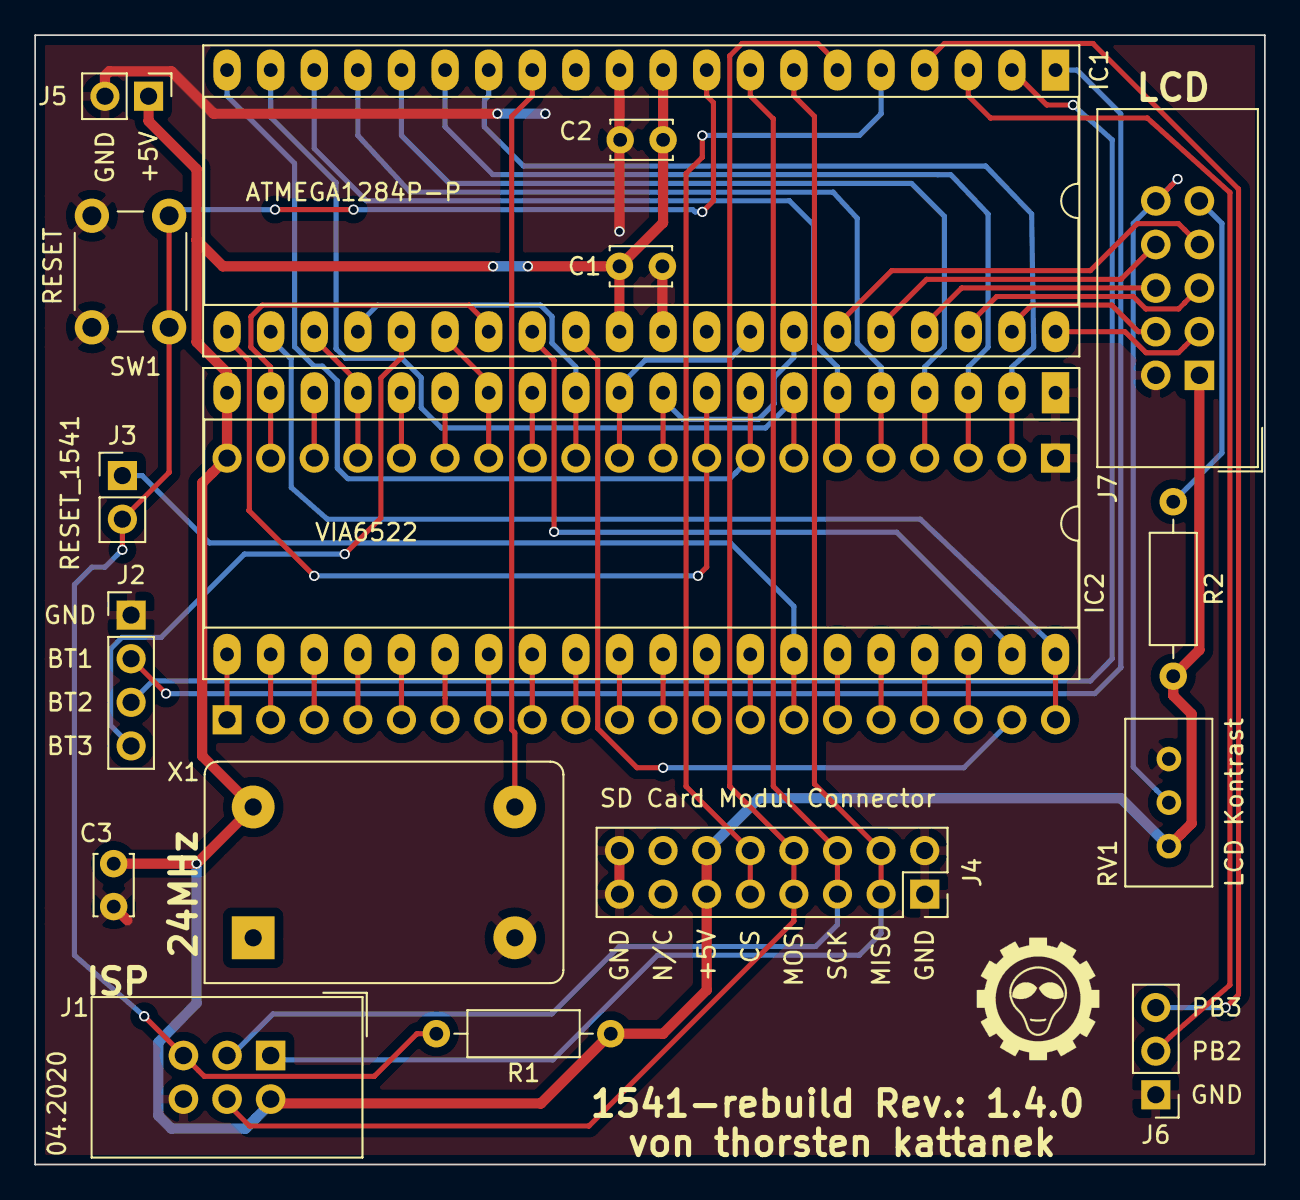
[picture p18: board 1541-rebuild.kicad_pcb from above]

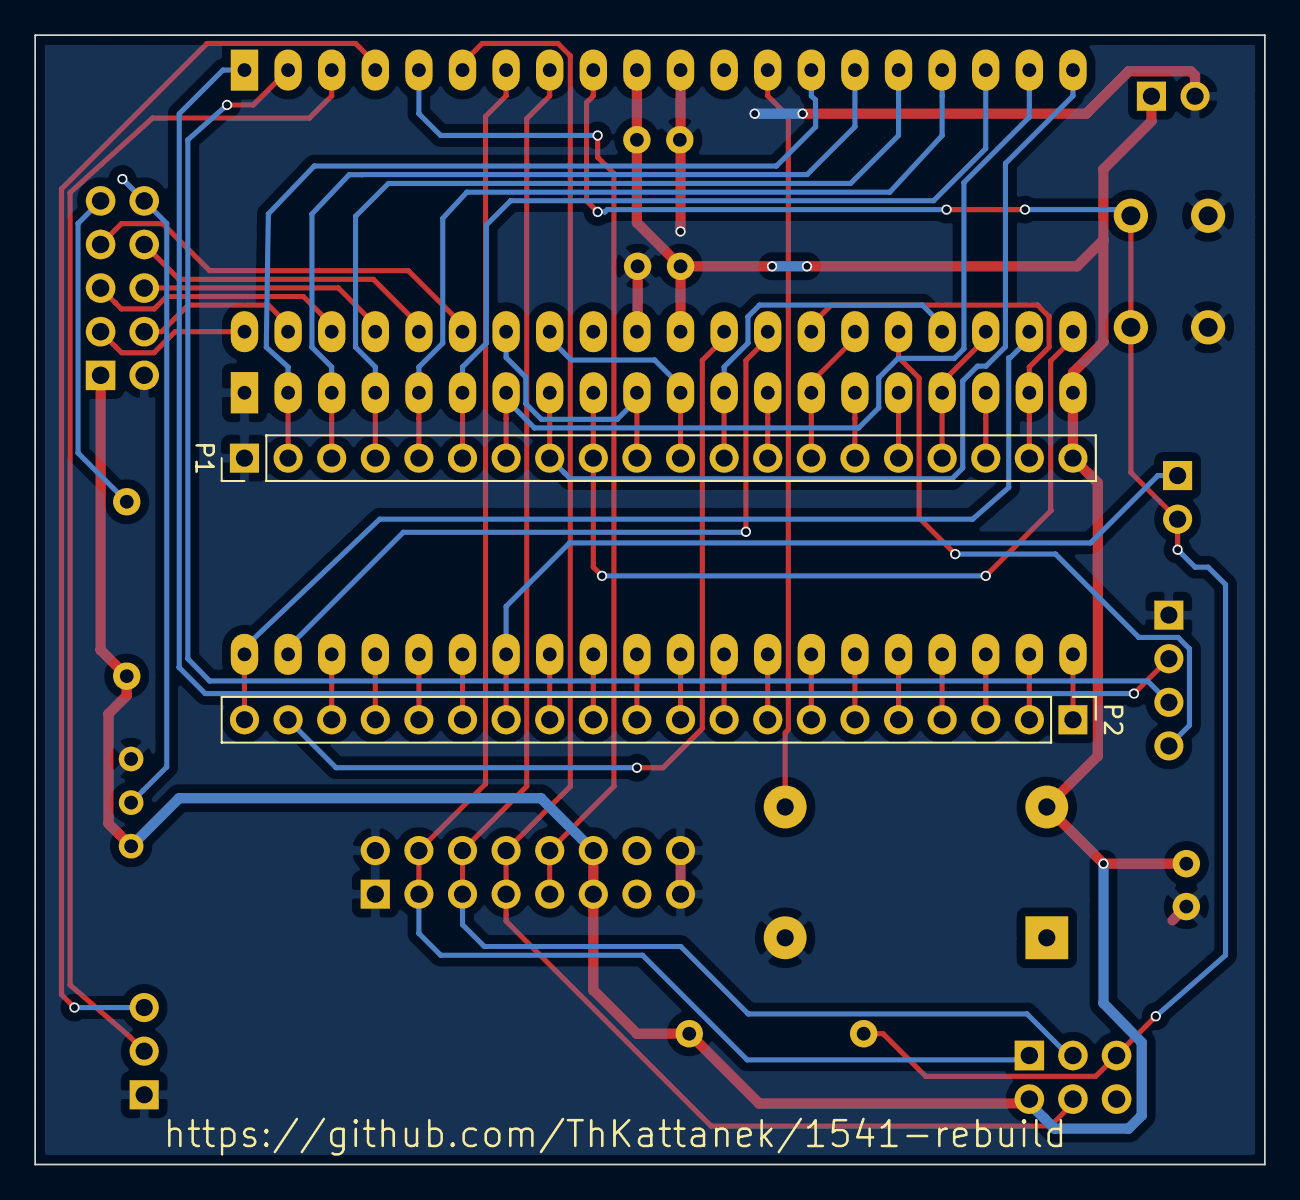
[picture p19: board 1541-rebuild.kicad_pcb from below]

Board: 2 copper layers, 71.6 x 65.8 mm, 19 parts (2 on the bottom side), 60 nets.

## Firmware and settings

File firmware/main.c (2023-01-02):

/* Name: main.c
* Project: 1541-rebuild
* Author: Thorsten Kattanek
* Copyright: (c) 2020 by Thorsten Kattanek <thorsten.kattanek@gmx.de>
* License: GPL 2
*/
// adoption for LCD I2C handling, D64 write-support
// implementation: F00K42
// last change: 17/12/2021

/// CPU Clock
#ifndef F_CPU
#define F_CPU 24000000UL
#endif

#include "./main.h"
#include <stdio.h>
#include <string.h>
#include <ctype.h>

/// \brief Anschluss für Drehgeber PIN A
#define PHASE_1A	(PINB & (1<<IMPULS_1A_PIN))
/// \brief Anschluss für Drehgeber PIN B
#define PHASE_1B	(PINB & (1<<IMPULS_1B_PIN))

/// \brief Decodierungstabelle für Drehgeber
const unsigned char drehimp_tab[16]PROGMEM = {0,0,2,0,0,0,0,0,1,0,0,0,0,0,0,0};

uint8_t id1 = 0;    // id1 and id2 identify a floppy-disk
uint8_t id2 = 0;    // - these need to change to .. signal a disk-change or after a format...

MENU_STRUCT main_menu;
MENU_STRUCT image_menu;
MENU_STRUCT settings_menu;
MENU_STRUCT info_menu;

enum  MENU_IDS{M_BACK, M_IMAGE, M_SETTINGS, M_INFO, \
               M_BACK_IMAGE, M_INSERT_IMAGE, M_REMOVE_IMAGE, M_WP_IMAGE, M_NEW_IMAGE, M_SAVE_IMAGE, \
               M_BACK_SETTINGS, M_PIN_PB2, M_PIN_PB3, M_SAVE_EEPROM, M_RESTART, \
               M_BACK_INFO, M_VERSION_INFO, M_SDCARD_INFO};

static uint8_t exit_main = 1;

int main(void)
{
    while(1)
    {
        exit_main = 1;
        reset();                // Alles initialisieren

        /// Menüs einrichten
        /// Hauptmenü
        MENU_ENTRY main_menu_entrys[] = {{"Disk Image",M_IMAGE,ENTRY_MENU,0,&image_menu},{"Settings",M_SETTINGS,ENTRY_MENU,0,&settings_menu},{"Info",M_INFO,ENTRY_MENU,0,&info_menu}};
        /// Image Menü
        MENU_ENTRY image_menu_entrys[] = {{"Insert Image",M_INSERT_IMAGE}, {"Remove Image",M_REMOVE_IMAGE}, {"Write Protect",M_WP_IMAGE,ENTRY_ONOFF,1}, {"New Image",M_NEW_IMAGE}, {"Save Image",M_SAVE_IMAGE}};
        /// Setting Menü
        MENU_ENTRY settings_menu_entrys[] = {{"Pin PB2",M_PIN_PB2, ENTRY_ONOFF, 0}, {"Pin PB3",M_PIN_PB3, ENTRY_ONOFF, 0}, {"Restart",M_RESTART}};
        /// Info Menü
        MENU_ENTRY info_menu_entrys[] = {{"Version",M_VERSION_INFO}, {"SD Card Info",M_SDCARD_INFO}};

        main_menu.lcd_cursor_char = 2;  // 126 Standard Pfeil
        menu_init(&main_menu, main_menu_entrys, 3,LCD_LINE_COUNT);

        image_menu.lcd_cursor_char = 2;  // 126 Standard Pfeil
        menu_init(&image_menu, image_menu_entrys, 5,LCD_LINE_COUNT);

        settings_menu.lcd_cursor_char = 2;  // 126 Standard Pfeil
        menu_init(&settings_menu, settings_menu_entrys, 3,LCD_LINE_COUNT);

        info_menu.lcd_cursor_char = 2;  // 126 Standard Pfeil
        menu_init(&info_menu, info_menu_entrys, 2,LCD_LINE_COUNT);

        menu_set_root(&main_menu);

        // Zeichen für Menü More Top setzen
        uint8_t char00[] = {4,14,31,0,0,0,0,0};
        lcd_generatechar(0, char00);
        fb_lcd_more_top_char = 0;


        // Zeichen für Menü More Down setzen
        uint8_t char01[] = {0,0,0,0,31,14,4,0};
        lcd_generatechar(1, char01);
        fb_lcd_more_down_char = 1;

        // Zeichen für Menü Position setzen
        uint8_t arrow_char[] = {0,4,6,31,6,4,0,0};
        lcd_generatechar(2, arrow_char);
        fb_lcd_cursor_char = 2;

        // Zeichen für Directory Symbol
        uint8_t dir_char[] = {0,28,31,17,17,31,0,0};
        lcd_generatechar(3, dir_char);
        fb_lcd_dir_char = 3;

        // Zeichen für Diskimage
        uint8_t diskimage_char[] = {15,27,17,27,31,27,27,31};
        lcd_generatechar(4, diskimage_char);
        fb_lcd_disk_char = 4;

        //// MAIN LOOP /////
        while(exit_main)
        {
            check_stepper_signals();
            check_motor_signal();
            update_gui();
        }

        release_sd_card();
    }
}

/////////////////////////////////////////////////////////////////////

void reset()
{
    // PB23 initialisieren
    init_pb2_pb3();

    // SOE GateArray initialisieren
    soe_gatearry_init();
    soe_gatearry_lo();      // Damit die GateArray das Signal Byte_Ready auf Hi setzt
                            // Somit stört mich das Signal nicht mehr und ich muss Byte_Ready
                            // Nur auf Lo ziehen (hi = hiz und lo = gnd)

    // Settings vom EEPROM prüfen
    if(eeprom_read_dword((uint32_t*)SETTINGS_IDENTIFIER) != 0x15411541)
    {
        settings_set_default_values(); // Default Values setzen
        reset();
    }

    // Tasten Initialisieren
    init_keys();

    // LCD Display intialisieren
    lcd_init();

    // Prüfen on Button2 gedrückt ist
    if(get_key2())
    {
        lcd_clear();
        lcd_setcursor(1,2);
        lcd_string("Changed Input Mode");

        if(eeprom_read_byte((uint8_t*)SETTINGS_INPUT_MODE) == INPUT_MODE_BUTTON)
        {
            eeprom_update_byte((uint8_t*)SETTINGS_INPUT_MODE, INPUT_MODE_ENCODER);
            lcd_setcursor(4,3);
            lcd_string("Encoder Mode");
        }
        else
        {
            eeprom_update_byte((uint8_t*)SETTINGS_INPUT_MODE, INPUT_MODE_BUTTON);
            lcd_setcursor(4,3);
            lcd_string("Button Mode");
        }
        _delay_ms(3000);
    }

    // Input Mode Setzen
    input_mode = eeprom_read_byte((uint8_t)SETTINGS_INPUT_MODE);

    // WPS PIN Enable
    endable_wps_port(1);

    // Startmeldung ausgeben
    show_start_message();

    // Stepper Initialisieren
    init_stepper();

    // Motor Initialisieren
    init_motor();

    // Steursignale BYTE_READY, SYNC und SOE Initialisieren
    init_controll_signals();

    // Image Remove
    remove_image();

    // Timer0 --> GCR senden
    init_timer0();

    // Timer2 --> wird alle 1ms aufgerufen
    // z.B. zu Tasten entprellen
    init_timer2();

    // Meldung ausgeben, das auf SD Karte gewartet wird
    lcd_setcursor(0,2);
    lcd_string("Wait for SD-Karte...");

    // SD Karte initialisieren
    // Partition und Filesystem öffnen
    // Warten bis alles O.K. ist
    while(init_sd_card())
    {
        _delay_ms(1000);
    }

    fb_dir_entry_count = get_dir_entry_count();

    // Key Puffer leeren
    key_buffer_r_pos = 0;
    key_buffer_w_pos = 0;

    // GUI Mode festlegen
    set_gui_mode(GUI_INFO_MODE);

    // Interrupts erlauben
    sei();
}

/////////////////////////////////////////////////////////////////////

void check_stepper_signals()
{
    // Auf Steppermotor aktivität prüfen
    // und auswerten
    if(stepper_signal_r_pos != stepper_signal_w_pos)    // Prüfen ob sich was neues im Ringpuffer für die Steppersignale befindet
    {
            uint8_t stepper = stepper_signal_puffer[stepper_signal_r_pos]>>2 | stepper_signal_puffer[stepper_signal_r_pos-1];
            stepper_signal_r_pos++;

        switch(stepper)
        {
        case 0x30: case 0x40: case 0x90: case 0xE0:
        // DEC
        stepper_dec();
            stepper_signal_time = 0;
            stepper_signal = 1;
        break;

        case 0x10: case 0x60: case 0xB0: case 0xC0:
        // INC
        stepper_inc();
            stepper_signal_time = 0;
            stepper_signal = 1;
        break;
        }
    }
    else if(stepper_signal && (stepper_signal_time >= STEPPER_DELAY_TIME))
    {
        stepper_signal = 0;

        if(!(akt_half_track & 0x01))
        {
            stop_timer0();

            // Geschwindigkeit setzen
            OCR0A = timer0_orca0[d64_track_zone[akt_half_track>>1]];
            akt_track_pos = 0;

            if(track_is_written == 1)
            {
                no_byte_ready_send = 1;

                track_is_written = 0;
                write_disk_track(fd,akt_image_type,old_half_track>>1,gcr_track, &gcr_track_length);

                read_disk_track(fd,akt_image_type,akt_half_track>>1,gcr_track, &gcr_track_length);
                old_half_track = akt_half_track;    // Merken um evtl. dort zurück zu schreiben

                no_byte_ready_send = 0;
            }
            else
            {
                read_disk_track(fd,akt_image_type,akt_half_track>>1,gcr_track, &gcr_track_length);
                old_half_track = akt_half_track;    // Merken um evtl. dort zurück zu schreiben
            }
            start_timer0();
        }
    }
}

/////////////////////////////////////////////////////////////////////

void check_motor_signal()
{
    if(!get_motor_status())
    {
        // Sollte der aktuelle Track noch veränderungen haben so wird hier erstmal gesichert.
        if(track_is_written == 1)
        {
            stop_timer0();
            no_byte_ready_send = 1;
            track_is_written = 0;
            write_disk_track(fd,akt_image_type,old_half_track>>1,gcr_track, &gcr_track_length);
            no_byte_ready_send = 0;
            start_timer0();
        }
    }
}

/////////////////////////////////////////////////////////////////////

uint8_t get_key_from_buffer()
{
    if(key_buffer_r_pos != key_buffer_w_pos)
    {
        uint8_t val = key_buffer[key_buffer_r_pos++];
        key_buffer_r_pos &= 0x0f;
        return  val;
    }
    else
        return NO_KEY;
}

/////////////////////////////////////////////////////////////////////

void update_gui()
{
    static uint8_t old_half_track = 0;
    static uint8_t old_motor_status = 0;
    static uint16_t wait_counter0 = 0;

    uint8_t key_code = get_key_from_buffer();

    switch (current_gui_mode)
    {
    case GUI_INFO_MODE:

        if(key_code == KEY2_UP)
            set_gui_mode(GUI_MENU_MODE);

        if(key_code == KEY2_TIMEOUT2)
            exit_main = 0;

        if(old_half_track != akt_half_track)
        {
            lcd_setcursor(7,1);
            lcd_string("   ");
            lcd_setcursor(7,1);
            sprintf (byte_str,"%d",akt_half_track >> 1);
            lcd_string(byte_str);
        }
        old_half_track = akt_half_track;

        if(old_motor_status != get_motor_status())
        {
            lcd_setcursor(7,2);
            if(get_motor_status())
                lcd_string("On ");
            else
                lcd_string("Off");
        }
        old_motor_status = get_motor_status();

        if(is_image_mount)
        {
            //// Filename Scrolling

            wait_counter0++;

            if(gui_current_line_offset > 0 && wait_counter0 == 30000)
            {
                wait_counter0 = 0;

                if(gui_line_scroll_end_begin_wait == 0)
                {
                    // Es darf gescrollt werden


                    if(!gui_line_scroll_direction)
                    {
                        gui_line_scroll_pos++;
                        if(gui_line_scroll_pos >= gui_current_line_offset)
                        {
                            gui_line_scroll_end_begin_wait = 6;
                            gui_line_scroll_direction = 1;
                        }
                    }
                    else
                    {
                        gui_line_scroll_pos--;
                        if(gui_line_scroll_pos == 0)
                        {
                            gui_line_scroll_end_begin_wait = 6;
                            gui_line_scroll_direction = 0;
                        }
                    }

                    lcd_setcursor(0,4);
                    lcd_print(image_filename,gui_line_scroll_pos,20);
                }
                else gui_line_scroll_end_begin_wait--;
            }
        }
        break;

    case GUI_MENU_MODE:
        check_menu_events(menu_update(key_code));
        break;

    case GUI_FILE_BROWSER:
        filebrowser_update(key_code);
        break;

    default:
        break;
    }
}

/////////////////////////////////////////////////////////////////////

void check_menu_events(uint16_t menu_event)
{
    uint8_t command = menu_event >> 8;
    uint8_t value = menu_event & 0xff;

    switch(command)
    {
    case MC_EXIT_MENU:
        set_gui_mode(GUI_INFO_MODE);
        break;

    case MC_SELECT_ENTRY:
        switch(value)
        {
        /// Main Menü

        /// Image Menü
        case M_INSERT_IMAGE:
            set_gui_mode(GUI_FILE_BROWSER);
            break;
        case M_REMOVE_IMAGE:
            remove_image();
            set_gui_mode(GUI_INFO_MODE);
            break;
        case M_WP_IMAGE:
            if(menu_get_entry_var1(&image_menu, M_WP_IMAGE))
            {
                set_write_protection(1);
            }
            else
            {
                set_write_protection(0);
            }
            menu_refresh();
            break;

        /// Settings Menü
        case M_PIN_PB2:
            if(menu_get_entry_var1(&settings_menu, M_PIN_PB2))
            {
                DDRB |= 1<<PB2;
            }
            else
            {
                DDRB &= ~(1<<PB2);
            }
            menu_refresh();
            break;

        case M_PIN_PB3:
            if(menu_get_entry_var1(&settings_menu, M_PIN_PB3))
            {
                DDRB |= 1<<PB3;
            }
            else
            {
                DDRB &= ~(1<<PB3);
            }
            menu_refresh();
            break;

        case M_SAVE_EEPROM:
            break;

        case M_RESTART:
            exit_main = 0;
            break;

        /// Info Menü
        case M_VERSION_INFO:
            show_start_message();
            menu_refresh();
            break;

        case M_SDCARD_INFO:
            show_sdcard_info_message();
            menu_refresh();
            break;
        }
        break;
    }
}

/////////////////////////////////////////////////////////////////////

void set_gui_mode(uint8_t gui_mode)
{
    current_gui_mode = gui_mode;
    switch(gui_mode)
    {
    case GUI_INFO_MODE:
        lcd_clear();

        lcd_setcursor(0,1);
        lcd_string("Track:");

        lcd_setcursor(7,1);
        sprintf (byte_str,"%d",akt_half_track >> 1);
        lcd_string(byte_str);

        lcd_setcursor(0,2);
        lcd_string("Motor:");

        if(get_motor_status())
            lcd_string(" On ");
        else
            lcd_string(" Off");

        lcd_setcursor(12,1);
        lcd_string("WP:");

        if(floppy_wp)
            lcd_string(" On");
        else
            lcd_string(" Off");

        if(is_image_mount)
        {
            lcd_setcursor(0,4);
            lcd_print(image_filename,0,20);

            // Für Scrollenden Filename
            int8_t var = (int8_t)strlen(image_filename) - 20;
            if(var < 0)
                gui_current_line_offset = 0;
            else
                gui_current_line_offset = var;
            gui_line_scroll_pos = 0;
            gui_line_scroll_direction = 0;
            gui_line_scroll_end_begin_wait = 6;
        }

        lcd_setcursor(2,4);
        if(!is_image_mount)
            lcd_string("No Image Mounted");

        break;
    case GUI_MENU_MODE:
        menu_refresh();
        break;
    case GUI_FILE_BROWSER:
        filebrowser_refresh();
        break;
    default:
        break;
    }
}

/////////////////////////////////////////////////////////////////////

void filebrowser_update(uint8_t key_code)
{
    uint16_t ret;
    char out_str[21];

    switch (key_code)
    {
    case KEY0_DOWN:
        if(fb_lcd_cursor_pos > 0)
        {
            fb_lcd_cursor_pos--;
            filebrowser_refresh();
        }
        else
        {
            if(fb_lcd_window_pos > 0)
            {
                fb_lcd_window_pos--;
                filebrowser_refresh();
            }
        }
        break;
    case KEY1_DOWN:
        if((fb_lcd_cursor_pos < LCD_LINE_COUNT-1) && (fb_lcd_cursor_pos < fb_dir_entry_count-1))
        {
            fb_lcd_cursor_pos++;
            filebrowser_refresh();
        }
        else
        {
            if(fb_lcd_window_pos < fb_dir_entry_count - LCD_LINE_COUNT)
            {
                fb_lcd_window_pos++;
                filebrowser_refresh();
            }
        }
        break;
    case KEY2_UP:
        stop_timer0();
        no_byte_ready_send = 1;

        close_disk_image(fd);

        if(fb_dir_entry[fb_lcd_cursor_pos].attributes & FAT_ATTRIB_DIR)
        {
            // Eintrag ist ein Verzeichnis
            change_dir(fb_dir_entry[fb_lcd_cursor_pos].long_name);
            fb_lcd_cursor_pos = 0;
            fb_lcd_window_pos = 0;
            filebrowser_refresh();
            return;
        }

        fd = open_disk_image(fs, &fb_dir_entry[fb_lcd_cursor_pos], &akt_image_type);

        if(akt_image_type == UNDEF_IMAGE)
        {
            lcd_clear();
            lcd_setcursor(0,2);
            lcd_string("Not Supported Image!");
            _delay_ms(1000);
        }

        filebrowser_refresh();

        strcpy(image_filename, fb_dir_entry[fb_lcd_cursor_pos].long_name);

        if(!fd)
        {
            is_image_mount = 0;
            return ;
        }

        read_disk_track(fd,akt_image_type,akt_half_track>>1,gcr_track, &gcr_track_length);
        akt_track_pos = 0;

        no_byte_ready_send = 0;
        start_timer0();

        is_image_mount = 1;
        send_disk_change();

        if(floppy_wp)
            menu_set_entry_var1(&image_menu, M_WP_IMAGE, 1);
        else
            menu_set_entry_var1(&image_menu, M_WP_IMAGE, 0);

        set_gui_mode(GUI_INFO_MODE);
        break;
    case KEY2_TIMEOUT1:
        set_gui_mode(GUI_MENU_MODE);
        break;
    }

    //// Filename Scrolling
    static uint16_t wait_counter0;
    wait_counter0++;

    if(fb_current_line_offset > 0 && wait_counter0 == 30000)
    {
        wait_counter0 = 0;

        if(fb_line_scroll_end_begin_wait == 0)
        {
            // Es darf gescrollt werden


            if(!fb_line_scroll_direction)
            {
                fb_line_scroll_pos++;
                if(fb_line_scroll_pos >= fb_current_line_offset)
                {
                    fb_line_scroll_end_begin_wait = 6;
                    fb_line_scroll_direction = 1;
                }
            }
            else
            {
                fb_line_scroll_pos--;
                if(fb_line_scroll_pos == 0)
                {
                    fb_line_scroll_end_begin_wait = 6;
                    fb_line_scroll_direction = 0;
                }
            }

            lcd_setcursor(2,fb_lcd_cursor_pos+1);
            lcd_print(fb_dir_entry[fb_lcd_cursor_pos].long_name,fb_line_scroll_pos,17);
        }
        else fb_line_scroll_end_begin_wait--;
    }
}

void filebrowser_refresh()
{
    lcd_clear();
    seek_to_dir_entry(fb_lcd_window_pos);

    uint8_t i=0;

    while(i<LCD_LINE_COUNT && ((fb_lcd_window_pos + i) < fb_dir_entry_count))
    {
        fat_read_dir(dd, &fb_dir_entry[i]);   // nächsten Directory Entry holen
        if(!(fb_dir_entry[i].attributes & (FAT_ATTRIB_SYSTEM | FAT_ATTRIB_VOLUME | FAT_ATTRIB_HIDDEN)))
        {
            lcd_setcursor(1,i+1);
            if(fb_dir_entry[i].attributes & FAT_ATTRIB_DIR)
                lcd_data(fb_lcd_dir_char);
            else
                lcd_data(' ');

            lcd_print(fb_dir_entry[i].long_name,0,17);

            i++;
        }
    }

    lcd_setcursor(0,fb_lcd_cursor_pos+1);
    lcd_data(fb_lcd_cursor_char);


    if(fb_lcd_window_pos > 0)
    {
        lcd_setcursor(19,1);
        lcd_data(fb_lcd_more_top_char);
    }

    if(fb_lcd_window_pos + LCD_LINE_COUNT < fb_dir_entry_count)
    {
        lcd_setcursor(19, LCD_LINE_COUNT);
        lcd_data(fb_lcd_more_down_char);
    }

    // Für Scrollenden Filename
    int8_t var = (int8_t)strlen(fb_dir_entry[fb_lcd_cursor_pos].long_name) - 17;
    if(var < 0)
        fb_current_line_offset = 0;
    else
        fb_current_line_offset = var;
    fb_line_scroll_pos = 0;
    fb_line_scroll_direction = 0;
    fb_line_scroll_end_begin_wait = 6;

}

/////////////////////////////////////////////////////////////////////

void init_pb2_pb3()
{
    DDRB &= ~(1<<PB2 | 1<<PB3);
    PORTB |= 1<<PB2 | 1<<PB3;
}

/////////////////////////////////////////////////////////////////////

int8_t init_sd_card(void)
{
    // LCD Fehlermeldung löschen
    lcd_setcursor( 0, 4);
    lcd_string("                    ");
    lcd_setcursor( 0, 4);

    set_sleep_mode(SLEEP_MODE_IDLE);

    // SD Karte initialisieren
    if(!sd_raw_init())
    {
        lcd_setcursor( 0, 4);
        lcd_string("err: sd_raw_init");
        return 1;
    }

    // Eine Partition öffnen (die erste)
    partition = partition_open(sd_raw_read,sd_raw_read_interval,sd_raw_write,sd_raw_write_interval,0);
    if(!partition)
    {
        partition = partition_open(sd_raw_read,sd_raw_read_interval,sd_raw_write,sd_raw_write_interval,-1);
        if(!partition)
        {
            lcd_setcursor( 0, 4);
            lcd_string("err: partition_open");
            return 2;
        }
    }

    // FAT16/32 Filesystem versuchen zu öffnen

    lcd_string("*");

    fs = fat_open(partition);

    lcd_string("*");

    if(!fs)
    {
        lcd_setcursor( 0, 4);
        lcd_string("err: fat_open");
        return 3;
    }

    // Root Verzeichnis öffnen
    fat_get_dir_entry_of_path(fs, "/", &dir_entry);
    dd = fat_open_dir(fs, &dir_entry);
    if(!dd)
    {
        lcd_setcursor( 0, 4);
        lcd_string("err: fat_open_root");
        return 4;
    }
    return 0;
}

/////////////////////////////////////////////////////////////////////

void release_sd_card()
{
    fat_close_dir(dd);
    fat_close(fs);
    partition_close(partition);
}

/////////////////////////////////////////////////////////////////////

uint8_t find_file_in_dir(struct fat_fs_struct* fs, struct fat_dir_struct* dd, const char* name, struct fat_dir_entry_struct* dir_entry)
{
    fat_reset_dir(dd);
    while(fat_read_dir(dd, dir_entry))
    {
        if(strcmp(dir_entry->long_name, name) == 0)
        {
            //fat_reset_dir(dd);
            return 1;
        }
    }
    return 0;
}

/////////////////////////////////////////////////////////////////////
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

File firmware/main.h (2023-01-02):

/* Name: main.h
* Project: 1541-rebuild
* Author: Thorsten Kattanek
* Copyright: (c) 2020 by Thorsten Kattanek <thorsten.kattanek@gmx.de>
* License: GPL 2
*/

// AVR Spezifische Headerdateien
#include <avr/io.h>
#include <util/delay.h>
#include <avr/interrupt.h>
#include <avr/sleep.h>
#include <avr/pgmspace.h>

// Für die LCD Ansteuerung
#include "./lcd.h"

// SDCard Lib
#include "./sd_card_lib/fat.h"
#include "./sd_card_lib/fat_config.h"
#include "./sd_card_lib/partition.h"
#include "./sd_card_lib/sd_raw.h"
#include "./sd_card_lib/sd_raw_config.h"

// Gui _ Menu
#include "./gui_constants.h"
#include "./menu.h"

// Enthält nur die Versionsnummer als String
#include "./version.h"

// Settings speichern in EEPROM und Import / Export
#include "./settings.h"

#define NULL    ((void *)0)

// Konfiguration /////////////////////////////////////////////////

// LCD
#define LCD_LINE_COUNT 4
#define LCD_LINE_SIZE 20

// Zeit in ms wie lange die Version nach dem Start angezeigt wird
#define START_MESSAGE_TIME 1500

// Spur auf dem der Lesekopf beim Start/Reset stehen soll
// Track 18 --> Directory
#define INIT_TRACK 18

// Zeit die nach der letzten Stepperaktivität vergehen muss, um einen neuen Track von SD Karte zu laden
// (1541 Original Rom schaltet STP1 alle 15ms)
// Default 15
#define STEPPER_DELAY_TIME 193  // zwischen 26µs*193=5,02ms bis 32µs*160=6,176ms

// SOE GATEWAY --> Ausgang
// LO wenn SD Karte laufen soll damit ByteReady High bleibt
#define SOE_GATEARRAY_DDR DDRC
#define SOE_GATEARRAY_PORT PORTC
#define SOE_GATEARRAY PC7

// Anschluss der Stepper Signale
// Zwingend diese PINs wegen Extern Interrupts PCINT6/7
// Bei Änderung muss der Sourcecode angepasst werden !
#define STP_DDR  DDRA
#define STP_PIN PINA
#define STP1 PINA6
#define STP0 PINA7

// Anschluss des Laufwerkmotor Signals
#define MTR_DDR DDRC
#define MTR_PIN PINC
#define MTR	PINC2

#define get_motor_status() (MTR_PIN & (1<<MTR))

// Steuersignale
// BYTE READY
#define BYTE_READY_DDR DDRC
#define BYTE_READY_PORT PORTC
#define BYTE_READY  PC0

//DDxn = 0 , PORTxn = 0 --> HiZ
//DDxn = 1 , PORTxn = 0 --> Output Low (Sink)

#define set_byte_ready() BYTE_READY_DDR &= ~(1 << BYTE_READY)   // HiZ
#define clear_byte_ready() BYTE_READY_DDR |= (1 << BYTE_READY)  // auf Ground ziehen

// SYNC
#define SYNC_DDR DDRC
#define SYNC_PORT PORTC
#define SYNC  PC1

#define set_sync() SYNC_PORT |= 1 << SYNC
#define clear_sync() SYNC_PORT &= ~(1 << SYNC)

// SOE
#define SOE_DDR DDRC
#define SOE_PIN PINC
#define SOE	PINC6

#define get_soe_status() (SOE_PIN & (1<<SOE))

// SO
#define SO_DDR DDRC
#define SO_PIN PINC
#define SO     PINC5

#define get_so_status() (SO_PIN & (1<<SO))

// WPS (Write Protection)
// PIN ist mit PIN14 U8 VIA6522 (Input) verbunden
// PIN ist mit PIN14 (A) GateArray (Input) verbunden
// PIN ist mit PIN8 LS04 DM74LS04N (Output) verbunden -> Einganag PIN9 hängt auf einen PullUp (47k)
#define WPS_DDR DDRC
#define WPS_PORT PORTC
#define WPS  PC4

#define set_wps() WPS_PORT |= 1 << WPS          // 5V Level = WritePotect
#define clear_wps() WPS_PORT &= ~(1 << WPS)     // 0V Level = Writetable

// Anschluss der Datenleitungen
#define DATA_DDR   DDRD
#define DATA_PORT  PORTD
#define DATA_PIN   PIND

#define out_gcr_byte(gcr_byte) DATA_PORT = gcr_byte
#define in_gcr_byte DATA_PIN

// Einabetasten
#define KEY0_DDR DDRB
#define KEY0_PORT PORTB
#define KEY0_PIN PINB
#define KEY0	 PINB0

#define KEY1_DDR DDRB
#define KEY1_PORT PORTB
#define KEY1_PIN PINB
#define KEY1	 PINB1

#define KEY2_DDR DDRC
#define KEY2_PORT PORTC
#define KEY2_PIN PINC
#define KEY2	 PINC3

#define get_key0() (~KEY0_PIN & (1<<KEY0))
#define get_key1() (~KEY1_PIN & (1<<KEY1))
#define get_key2() (~KEY2_PIN & (1<<KEY2))

// Drehimpulsgeber // Liegen immer auf KEY0 + KEY1
/// \brief Pin Nummer des Ports für Drehgeber PIN 1A
#define IMPULS_1A_PIN KEY1
/// \brief Port für Drehgeber PIN 1A
#define IMPULS_1A_PORT KEY1_PORT
/// \brief Datenrichtungsregister des Ports für Drehgeber PIN 1A
#define IMPULS_1A_DDR KEY1_DDR

/// \brief Pin Nummer des Ports für Drehgeber PIN 1B
#define IMPULS_1B_PIN KEY0
/// \brief Port für Drehgeber PIN 1B
#define IMPULS_1B_PORT KEY0_PORT
/// \brief Datenrichtungsregister des Ports für Drehgeber PIN 1B
#define IMPULS_1B_DDR KEY0_DDR

//////////////////////////////////////////////////////////////////
// #define __AVR_ATmega128__

enum {UNDEF_IMAGE, G64_IMAGE, D64_IMAGE};
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

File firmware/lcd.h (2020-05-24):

// Ansteuerung eines HD44780 kompatiblen LCD im 4-Bit-Interfacemodus
// http://www.mikrocontroller.net/articles/AVR-GCC-Tutorial/LCD-Ansteuerung
//
 
#ifndef LCD_ROUTINES_H
#define LCD_ROUTINES_H
 
////////////////////////////////////////////////////////////////////////////////
// Hier die verwendete Taktfrequenz in Hz eintragen, wichtig!
 
#ifndef F_CPU
#define F_CPU 24000000UL
#endif
 
////////////////////////////////////////////////////////////////////////////////
// Pinbelegung für das LCD, an verwendete Pins anpassen
// Alle LCD Pins müssen an einem Port angeschlossen sein und die 4
// Datenleitungen müssen auf aufeinanderfolgenden Pins liegen
 
//  LCD DB4-DB7 <-->  PORTB Bit PB0-PB3
#define LCD_PORT      PORTA
#define LCD_DDR       DDRA
#define LCD_DB        PA0
 
//  LCD RS      <-->  PORTB Bit PB4     (RS: 1=Data, 0=Command)
#define LCD_RS        PA4
 
//  LCD EN      <-->  PORTB Bit PB5     (EN: 1-Impuls für Daten)
#define LCD_EN        PA5
 
////////////////////////////////////////////////////////////////////////////////
// LCD Ausführungszeiten (MS=Millisekunden, US=Mikrosekunden)
 
#define LCD_BOOTUP_MS           15 	// 15
#define LCD_ENABLE_US           20	// 20
#define LCD_WRITEDATA_US        46	// 46
#define LCD_COMMAND_US          42	// 42
 
#define LCD_SOFT_RESET_MS1      5	// 5
#define LCD_SOFT_RESET_MS2      1	// 1
#define LCD_SOFT_RESET_MS3      1	// 1
#define LCD_SET_4BITMODE_MS     5	// 5
 
#define LCD_CLEAR_DISPLAY_MS    2	// 2	
#define LCD_CURSOR_HOME_MS      2	// 2
 
////////////////////////////////////////////////////////////////////////////////
// Zeilendefinitionen des verwendeten LCD
// Die Einträge hier sollten für ein LCD mit einer Zeilenlänge von 20 Zeichen passen
// Bei anderen Zeilenlängen müssen diese Einträge angepasst werden
 
#define LCD_DDADR_LINE1         0
#define LCD_DDADR_LINE2         64
#define LCD_DDADR_LINE3         20
#define LCD_DDADR_LINE4         84
 
////////////////////////////////////////////////////////////////////////////////
// Initialisierung: muss ganz am Anfang des Programms aufgerufen werden.
void lcd_init( void );
 
////////////////////////////////////////////////////////////////////////////////
// LCD löschen
void lcd_clear( void );
 
////////////////////////////////////////////////////////////////////////////////
// Cursor in die 1. Zeile, 0-te Spalte
void lcd_home( void );
 
////////////////////////////////////////////////////////////////////////////////
// Cursor an eine beliebige Position 
void lcd_setcursor( uint8_t spalte, uint8_t zeile );
 
////////////////////////////////////////////////////////////////////////////////
// Ausgabe eines einzelnen Zeichens an der aktuellen Cursorposition 
void lcd_data( uint8_t data );
 
////////////////////////////////////////////////////////////////////////////////
// Ausgabe eines Strings an der aktuellen Cursorposition 
void lcd_string( const char *data );
 
////////////////////////////////////////////////////////////////////////////////
// Schreibt einen String auf das LCD mit erweiterten Parametern
// start:   Position des erstes Zeichens im String was ausgegeben werden soll
// length:  Maximale Anzahl der Zeichen die Ausgegeben werden sollen
void lcd_print(char *string, uint8_t start, uint8_t length);

////////////////////////////////////////////////////////////////////////////////
// Definition eines benutzerdefinierten Sonderzeichens.
// data muss auf ein Array[8] mit den Zeilencodes des zu definierenden Zeichens
// zeigen
void lcd_generatechar( uint8_t code, const uint8_t *data );
 
////////////////////////////////////////////////////////////////////////////////
// Ausgabe eines Kommandos an das LCD.
void lcd_command( uint8_t data );
 
 
////////////////////////////////////////////////////////////////////////////////
// LCD Befehle und Argumente.
// Zur Verwendung in lcd_command
 
// Clear Display -------------- 0b00000001
#define LCD_CLEAR_DISPLAY       0x01
 
// Cursor Home ---------------- 0b0000001x
#define LCD_CURSOR_HOME         0x02
 
// Set Entry Mode ------------- 0b000001xx
#define LCD_SET_ENTRY           0x04
 
#define LCD_ENTRY_DECREASE      0x00
#define LCD_ENTRY_INCREASE      0x02
#define LCD_ENTRY_NOSHIFT       0x00
#define LCD_ENTRY_SHIFT         0x01
 
// Set Display ---------------- 0b00001xxx
#define LCD_SET_DISPLAY         0x08
 
#define LCD_DISPLAY_OFF         0x00
#define LCD_DISPLAY_ON          0x04
#define LCD_CURSOR_OFF          0x00
#define LCD_CURSOR_ON           0x02
#define LCD_BLINKING_OFF        0x00
#define LCD_BLINKING_ON         0x01
 
// Set Shift ------------------ 0b0001xxxx
#define LCD_SET_SHIFT           0x10
 
#define LCD_CURSOR_MOVE         0x00
#define LCD_DISPLAY_SHIFT       0x08
#define LCD_SHIFT_LEFT          0x00
#define LCD_SHIFT_RIGHT         0x04
 
// Set Function --------------- 0b001xxxxx
#define LCD_SET_FUNCTION        0x20
 
#define LCD_FUNCTION_4BIT       0x00
#define LCD_FUNCTION_8BIT       0x10
#define LCD_FUNCTION_1LINE      0x00
#define LCD_FUNCTION_2LINE      0x08
#define LCD_FUNCTION_5X7        0x00
#define LCD_FUNCTION_5X10       0x04
 
#define LCD_SOFT_RESET          0x30
 
// Set CG RAM Address --------- 0b01xxxxxx  (Character Generator RAM)
#define LCD_SET_CGADR           0x40
 
#define LCD_GC_CHAR0            0
#define LCD_GC_CHAR1            1
#define LCD_GC_CHAR2            2
#define LCD_GC_CHAR3            3
#define LCD_GC_CHAR4            4
#define LCD_GC_CHAR5            5
#define LCD_GC_CHAR6            6
#define LCD_GC_CHAR7            7
 
// Set DD RAM Address --------- 0b1xxxxxxx  (Display Data RAM)
#define LCD_SET_DDADR           0x80
 
#endif 

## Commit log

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2015-09-14 Angefangen den aktuellen Schaltplan mit KiCad zu zeichnen
    [1541-rebuild.sch]
2015-09-15 Im Schaltplan die SD Karten Anbindung eingefügt
    [1541-rebuild.sch, sd_karte.sch]
2015-09-15 Hinweistext zur Modifikation der 1541 Platine hinzugefügt
    [1541-rebuild.sch]
2015-09-15 .bak Dateien aus Repo entfernt.Qscillator im Schaltpan hinzugefügt
    [1541-rebuild.sch, sd_karte.sch]
2015-09-15 Weiter am Schaltplan gezeichnet ... noch sehr Fehlerhaft
    [1541-rebuild.sch, sd_karte.sch]
2015-09-15 Schaltplan angepasst.Motor von PortA auf PortC verlegt.
    [1541-rebuild.sch, sd_karte.sch]
2015-09-16 Schaltplan weiter entwickelt und Layout angefangen
    [1541-rebuild.kicad_pcb, 1541-rebuild.sch, lcd.sch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]
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2015-09-20 Sourcecode neu überarbeitet, Schaltplan angepasst und DOC bearbeitet
    [1541-rebuild.sch, lcd.sch, sd_karte.sch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]
2015-09-20 Schaltplan angepasst und Firmware angepasst
    [1541-rebuild.sch, lcd.sch, sd_karte.sch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]
2015-09-20 WPS Signal zum Diskwechsel anzeigen eingebaut. Laden des Track18 eines ausgewählten G64. Schaltpaln aktuallisiert
    [1541-rebuild.sch, via6522_sockel.sch]
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2015-09-30 Im Schaltplan OE an µC PC5 angeschlossen.
    [1541-rebuild.sch]
2015-10-03 Fix: Elvira Arcade und Caren1.1 laufen jetzt auch
    [main.c, main.h]
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2016-09-10 Die 3 Taster müssen auf GND liegen und nich auf +5V ! Es werden die internen PullUps des µC verwendet.
    [1541-rebuild.sch, lcd.sch, sd_karte.sch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]
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2017-03-28 diverese Sachen geändert
    [1541-rebuild.csv, 1541-rebuild.kicad_pcb, 1541-rebuild.sch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]
2017-04-02 Platine per Autorouter geroutet.
    [1541-rebuild.csv, 1541-rebuild.dsn, 1541-rebuild.kicad_pcb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]
2017-04-02 Logo in PCB eingefügt
    [1541-rebuild.kicad_pcb]
2018-04-07 PCB Board gelöscht um mit älteren KiCad Versionen kompatibel zu sein.
    [1541-rebuild.kicad_pcb, 1541-rebuild.sch]
2018-04-18 Debug LED im Schaltplan eingefügt.
    [1541-rebuild.sch, lcd.sch, sd_karte.sch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]
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2018-04-18 Schaltplan angepasst. Reset kann optional per Jumper zwischen uController und Floppy Elektronik verbunden werden. Somit wird die Adapterplatine resettet wenn der C64 neu gestartet wird.
    [1541-rebuild.sch, via6522_sockel.sch]
2018-04-18 BugFix: Stepperänderung wurde nicht mehr erkannt. Und somit kein laden mehr möglich gewesen. Problem war eine zu frühe Zeiger erhöhung.
    [main.c]
2018-04-21 Änderungen am Schaltplan: - Resettaster eingefügt - SD Card Slot -> WP und DETECT richtig angeschlossen - auf Version 1.2 hochgesetzt
    [1541-rebuild.sch, lcd.sch, sd_karte.sch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]
2018-04-22 G64 Support -> Bugfix -> G64 lesen geht nun Schreiben auf G64 funktioniert auch. D64 noch nicht! BugFix -> ComaLight 13 absturtz nach wechsel auf Seite 2 -> läuft jetzt
    [main.c, main.h]
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2018-04-22 Komando zurück --> no_send_ready bleibt vorrerst drin ! Sonst gibt es probleme beim schreiben (StopTimer0 reicht nicht)
    [main.c, main.h]
2018-04-22 Alte Timingtabelle für die 4 TimeZonen der Floppy wieder aktiviert. Die neu Korrigierte mit "Align the 1541 Drive" habe ich auskommentiert.
    [main.h]
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2018-05-04 Schaltplan angepasst und Takt auf 24MHz geändert. Revision auf 1.2.1 gesetzt.
    [1541-rebuild.sch, lcd.sch, sd_karte.sch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]
2018-05-05 Im Schaltplan die Debug LED mit Vorwiderstand durch einen PIN Header ersetz für eventuelle Erweiterung. Auf Revision 1.3 gesetzt
    [1541-rebuild.sch, lcd.sch, sd_karte.sch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]
2018-05-05 LCD Display wird nun als 10 PIN Wannenstecker rausgeführt. PIN Belegung des Steckers wird im Schaltplan beschrieben.
    [1541-rebuild.sch, lcd.sch, sd_karte.sch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]
2018-05-05 Im Schaltplan die 3 Steuertasten als 4 PINS (Key1, Key2, Key3 und GND) rausgeführt. Auf Revesion 1.3.2 gesetzt.
    [1541-rebuild.sch, lcd.sch, sd_karte.sch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]
2018-05-06 Jumper für EXT_5V hinzugefügt. Schaltplan aufgeräumt. Schaltplan auf Revision 1.3.3 gesetzt.
    [1541-rebuild.sch, lcd.sch, sd_karte.sch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]
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2018-05-06 ERC Check Fehler behoben. GND + +5V PIN auf Power Out gestellt.
    [1541-rebuild.sch, lcd.sch, sd_karte.sch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]
2018-05-06 Allen Bauteilen Footprints zugeordnet.
    [1541-rebuild.sch, lcd.sch, sd_karte.sch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]
2018-05-06 - Anordnung aller Bauteile (Problem noch mit SD-Slot) - Erstes PCB Layout mit Freeroute - Autorouter.
    [1541-rebuild.dsn, 1541-rebuild.kicad_pcb, 1541-rebuild.sch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]
2018-05-06 Testweise Gerber Dateien erzeugt um diese auf Seedstudio zu testen.
    [1541-rebuild-B.Cu.gbl, 1541-rebuild-B.Mask.gbs, 1541-rebuild-B.SilkS.gbo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]
2018-05-08 BOM als csv in der doc hinzugefügt
    [1541-rebuild-bom.csv]
2018-05-08 - Hardware nochmal angepasst - erstes Layout erstellt - Schaltplan auf Rev.1.3.4 gesetzt
    [1541-rebuild-B.Cu.gbl, 1541-rebuild-B.Mask.gbs, 1541-rebuild-B.SilkS.gbo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]
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2018-05-11 Borad fertig gestellt und auf rev 1.3.5 gesetzt Gerberfiles erzeugt und als rar gepackt. Mit PCB Hersteller -Seedstudio- getestet.
    [1541-rebuild-bom.csv, 1541-rebuild.dsn, 1541-rebuild.kicad_pcb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]
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2018-05-16 Bezugsquellen für den SD Slot im Schaltplan hinzugefügt.
    [1541-rebuild.sch, lcd.sch, sd_karte.sch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]
2020-04-14 Hardware Projekt knovertiert von KiCad 4 -> KiCad 5 - Schaltplan angepasst - neues Detailfoto hinzugefügt - Footprints neu zugeordnet, somit ist auch wieder eine 3D Darstellung möglich - Readme.md an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
    [1541-rebuild.kicad_pcb, 1541-rebuild.sch, lcd.sch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]
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2020-04-16 Schaltplan angepasst: - SD Card Slot entfernt - SD Card Modul Connector hinzugefügt - im PCB alle Leiterbahne entfernt
    [1541-rebuild.kicad_pcb, 1541-rebuild.sch, lcd.sch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]
2020-04-17 Platine geändert - größe angepasst für 1541 I + II - Bauteile neu angeordnet - Beschriftungen hinzugefügt
    [1541-rebuild.kicad_pcb, 1541-rebuild.sch, lcd.sch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]
2020-04-17 Platine geändert - größe nochmals angepasst an 1541 II, 1541 kurz, 5141 mittel - Bauteile neu angeordnet
    [1541-rebuild.kicad_pcb, 1541-rebuild.sch, lcd.sch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]
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2020-04-18 readme.md geändert - Text überarbeitet - neues Bild eingefügt
    [1541-rebuild.kicad_pcb]
2020-04-18 Platine geändert - link zum GitHub Repository als Beschriftung hinzugefügt
    [1541-rebuild.kicad_pcb]
2020-04-18 Platine geändert - Byte Ready Signal muss nicht mehr am GateArray durchtrennt werden - SOE zwischen VIA und VIA Pinheader getrennt - SOE des Pinheader geht zum PIN PC7 des Atmega
    [1541-rebuild.kicad_pcb, 1541-rebuild.sch, lcd.sch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]
2020-04-18 firmware angepasst an neues pcb layout - SOE am GateArray kann nun vom AtMega getseuert werden, für 1541-rebuild muss das auf lo gesetzt werden - damit ist ByteReady dauerhaft auf Hi und kann auch so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
    [main.c, main.h]
2020-04-18 Gerberfiles für PCB Rev. 1.4.0 hinzugefügt
    [1541-rebuild.kicad_pcb]
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2020-04-30 bom angepasst - LCD Modul hinzugefügt - SD Card Modul hinzugefügt
    [1541-rebuild_bom.ods]
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2020-05-21 Firmware: - fixed SetUserChar in lcd_widget.cpp - in MENU_STRUCT -> lcd_cursor_char hinzugefügt
    [main.c]
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2020-05-23 Firmware: - seek_to_dir_entry korrigiert --> funktioniert nun
    [main.c]
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2021-12-04 D64 write support implemented
    routines taken from fook42/1541-rebuild fork.
    GCR decoding according to lft description - improved
    pointer handling and combined lookup table for better
    performance.
    known issues: writing of multiple tracks leads to data corruption
    [main.c, main.h]
2021-12-20 D64: extraction of Floppy-IDs from Track18-Area
    reads 2 bytes from Track18 - Offset $A2+$A3 and stores it in
    global variables for GCR track creation.
    fixes issue #33
    [main.c]
2021-12-20 D64: extraction of FloppyID .. fixed typecast to int32_t
    [main.c]
2021-12-20 D64: extraction of FloppyID .. fixed track_nr=18 value
    [main.c]
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
